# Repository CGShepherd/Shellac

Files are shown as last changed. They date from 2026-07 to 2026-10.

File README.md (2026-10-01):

# Project Shellac

Shellac is a controlled 78 rpm replay preamplifier design. `develop` is the working engineering authority; a tagged `main` release becomes production authority only after qualification and reproducibility gates close.

## Current authority

Read these first:

1. `config/decisions/current_decision_index.yaml`
2. `config/decisions/document_authority.yaml`
3. `docs/knowledge/DESIGN_PACK_INDEX.md`
4. current `generator/`, BOM and tests
5. current pre-SPICE assurance records in `docs/design_pack/`

Historical records are provenance and do not override later current authority.

## Live implementation versus selected-next architecture

- DR-037 complete RIAA: implemented.
- DR-038/SCH101: AE-071A migrates the fail-safe 14/18/22 dB removable-shunt architecture and BASE/+47/+100 pF loading; AE-075B selects LT5400BIMS8E-7#PBF, bonds EP9 to quiet 0VA and selects compatible Samtec TSW/MNT service hardware. RUN10 complete-stage tolerance/CMRR, physical shunt pairing/orientation, short-route parasitics and bench qualification remain open.
- DR-039/SCH107: AE-074 migrates the AE-067 branch-local topology into the live generator: the retained 1 uF / 330 kOhm network exists only in each DIRECT/BYPASS branch, while the existing SCH107 high-pass branch provides intrinsic DC blocking. Native-PCB F8/net reconciliation is closed by AE-074; RUN09, RUN10, RUN12 and bench correlation remain open.
- SCH108/output interface: AE-075G implements exact Molex 5055780221 two-circuit PCB headers H801/H802 for the short rear-panel balanced-output looms, validates HOT/COLD native pad mapping with no 0VA conductor, corrects THAT1646 source semantics to 25 Ohm per leg / 50 Ohm differential, and passes the application-specific PRE90 2 kOhm load discriminator. H801/H802 XY remains provisional pending manual placement reconciliation; RUN06 load/cable stability and dynamic-THD bench gates remain open.
- AE-041 A1 + AE-075C hardware + AE-076B controls: exact NKK/C&K hardware remains frozen. AE-076B supersedes the AE-075D/E/F four-local-control-board/carrier-era ownership architecture with one main audio PCB carrying all seven controls directly; the upper cover, main PCB and controls form one removable service module. Six PCB-to-upper-cover supports are selected in principle, but exact support XY/Z, the C&K fit at the NKK-constrained control plane, control XY, footprints/courtyards, panel apertures and RUN10 parasitic acceptance remain B03-open. SR-040/AE-071B MH1-MH4 native geometry is retained only as interim physical CAD pending the AE-076B2 MCAD/digital-mock-up migration; no control inter-board harnesses are selected.
- SW905 mute: mechanical DPDT signal/0VA selection immediately before the THAT1646 drivers. No relay/timer/comparator architecture.

Do not change live circuitry merely to make it resemble a selected-next record. Migration requires a controlled qualification and implementation step.

## Power and grounding

AE-076A establishes +17.0 V / 0VA / -17.0 V as current Shellac regulated-rail authority and migrates the live generator, current simulation contract, commissioning expectations and native PCB rail identities together. Historical +/-18 V assurance evidence remains immutable provenance. AE-073's target-17 PSU discriminator remains supporting model evidence only: powered set-point, dropout, ripple, startup and thermal qualification remain open under RUN13/RUN14 and bench work. The selected direct 0VA-to-chassis population remains R909 = 0 Ohm fitted, with C909, D901 and D902 DNP. Shellac and Phoenix are independent designs.

## Simulation

AE-053 defines the LTspice/Python simulation architecture. AE-054 through AE-058 establish implemented toolchain and numerical-correlation evidence. The integrated full-system campaign remains governed by AE-048 and AE-050 with AE-049 retained as the historical numerical-acceptance basis; AE-076A narrowly supersedes the current nominal-RUN00 rail criterion at +17 V / 0VA / -17 V and adds targeted rail/headroom requalification. Analytical Python is an independent live-state regression/correlation aid, not final integrated analogue authority.

## Basic validation

    python -m pytest -q
    python tools/audit_current_decision_index.py
    git diff --check

This repository is not yet a manufacturing baseline.

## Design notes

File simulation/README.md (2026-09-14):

# Project Shellac — Controlled LTspice/Python Toolchain

This directory implements the AE-053 simulation architecture under the governing
qualification/acceptance/execution authorities AE-048, AE-049 and AE-050.

Stage 1 scope is deliberately narrow:

- controlled tool/version discovery;
- deterministic run configuration;
- model/include provenance and SHA-256 manifests;
- reproducible LTspice batch invocation;
- structured measurement extraction;
- central acceptance mapping;
- RUN00 model-sanity harness;
- anomaly recording;
- deterministic rerun comparison.

This stage does **not** implement DR-038 or DR-039 circuit changes and does not
constitute manufacturing authority.

## First use

From the repository root:

```cmd
python -m simulation.scripts.shellac_spice doctor
python -m simulation.scripts.shellac_spice manifest
python -m simulation.scripts.shellac_spice prepare RUN00
```

If LTspice is installed and discovered:

```cmd
python -m simulation.scripts.shellac_spice run RUN00
python -m simulation.scripts.shellac_spice verify RUN00
```

If LTspice is not auto-discovered, set `LTSPICE_EXE` to the full executable path.

Generated artefacts live under `simulation/generated`, `simulation/results`,
`simulation/logs`, and `simulation/plots`. They are reproducible artefacts rather
than hand-edited design authority.

RUN00 is a toolchain/invocation sanity circuit, not the final integrated Shellac model.
Its purpose is to prove the controlled execution path before real block models are added.

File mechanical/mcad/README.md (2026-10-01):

# Shellac MCAD workspace

AE-076B2 controls this workspace.

METCASE M5502119:
- public official PDF drawing is hash-controlled;
- exact STEP requires METCASE authentication and is ingested/hash-controlled by AE-076B2B;
- drawing-to-STEP dimensional reconciliation remains open.

Neutrik panel STEP models and the governed KiCad PCB STEP live only in ignored
local evidence caches.

Reproduce public/local inputs with:

    .venv\Scripts\python.exe tools\prepare_ae076b2b_mcad_inputs.py

After manually downloading M5502119.stp while logged in to METCASE:

    .venv\Scripts\python.exe tools\prepare_ae076b2b_mcad_inputs.py --verify-only --ingest-metcase-step "C:\path\M5502119.stp"

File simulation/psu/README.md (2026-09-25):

# Shellac PSU simulation

The PSU simulation namespace separates manufacturer-macromodel execution qualification
from physical PSU qualification.

- `config/p1v.yaml` is the current AIYIMA P1-V physically reconstructed authority,
  pending powered validation.
- `RUN00_QUALIFICATION.md` records the controlled model-execution qualification.
- RUN00 is PASS locally; AE-073 closes the long-settle discriminator and confirms
  that the exploratory 400 ms low-output condition was a startup-settling artefact,
  not a demonstrated DC adjustment ceiling. Powered hardware qualification remains open.
- Compact AE-073 evidence is retained under `evidence/ae073_long_settle/`.
- Vendor model payloads are local only and are not committed.
- The governing philosophy is retain the as-fitted PSU unless quantitative analysis
  or measurement identifies a material safety, reliability, stability, noise,
  regulation, thermal, protection or operating-margin deficiency.

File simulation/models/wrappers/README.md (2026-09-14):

# Model wrappers

Controlled wrappers/adaptors around unchanged reference models belong here.

A wrapper must state:
- reference model wrapped;
- interface/pin mapping;
- reason;
- limitations;
- claims for which it is suitable.

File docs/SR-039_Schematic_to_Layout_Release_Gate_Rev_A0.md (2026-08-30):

# SR-039 — Schematic-to-Layout Release Gate — Rev A0

## Executive disposition

Project Shellac's electrical/schematic design is **released for layout work**.

Validated baseline:
- 374 / 374 Python regression tests;
- successful generated KiCad project build;
- native KiCad ERC: **0 errors, 0 warnings**.

DR-037, DR-038, DR-039 and DR-040 are treated as implemented. The signal-chain
architecture is frozen for layout unless a new controlled defect is demonstrated.

## Released now

- SCH101 precision balanced front end with 4.000x LT5400-7 architecture.
- SCH103 complete replay EQ and DR-039 common post-EQ DC isolation.
- SCH107 rumble filter.
- SCH104 final gain.
- SCH105 channel-mode matrix.
- SCH108 balanced output and mute.
- SCH109 controls/interfaces.
- Four-layer analogue PCB architecture and critical-net policy.

## Not yet released

### Final routing
The active board-outline model still uses provisional mechanical datums.
Critical-cluster placement may proceed inside the conservative provisional
220 x 140 mm keep-in, but mounting holes, enclosure intrusion keep-outs and final
harness corridors must not be invented.

### Manufacturing
The controlled BOM remains a partial high-level baseline rather than a full
schematic-population procurement BOM. Manufacturing release therefore requires
exact identities, quantities, footprints and procurement state for the complete board.

## Layout-critical constraints

SCH101:
- preserve cartridge-pair symmetry through RF filtering;
- keep each LT5400 adjacent to its OPA1656 converter;
- PLUS_SUM / MINUS_SUM and PRE_EQ feedback/output nodes are manual, zero-via critical nets;
- no power/control copper through the cartridge or LT5400 summing region.

SCH103:
- C360/C410 1 uF DR-039 film capacitors and R360/R410 330 k bias resistors
  stay at the recovery-output / POST_EQ hand-off;
- timing/selector branches remain local to each channel;
- preserve physical separation between left and right EQ islands.

SCH107:
- frequency-setting passives remain tight to the OPA1656 stage.

SCH108:
- THAT1646 OUT/SNS loops remain direct, local and zero-via where practicable.

Power / ground:
- Inner-1 remains continuous 0VA.
- CHASSIS is not a signal-current return.
- ±18 V load returns must not traverse cartridge/EQ reference regions.

## Next phase

SR-040 is the **mechanical-datum + full-BOM + critical-placement closure**.
It should end with:
1. frozen board outline and mounting holes;
2. full keep-out map;
3. complete BOM/footprint/procurement reconciliation;
4. accepted placement of all critical analogue clusters;
5. routing release.

Once SR-040 closes, routing should start immediately.

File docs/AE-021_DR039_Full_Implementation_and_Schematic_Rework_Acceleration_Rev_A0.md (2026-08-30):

# AE-021 — DR-039 Full Implementation and Schematic-Rework Acceleration

This phase closes DR-039 as an implemented subsystem rather than another analysis increment. SCH103 gains a common 1 µF PET-film / 330 kΩ DC block per channel before the SCH107 FILTER/BYPASS split, with raw and post-block test points. The nominal pole is approximately 0.48 Hz and is negligible at 20 Hz.

Physical capture uses the WIMA MKS2 1 µF / 63 V class, 5 mm lead pitch, approximately 7.2 × 5 × 10 mm.

After this phase, the only major signal-chain schematic rework before layout is DR-038 SCH101 precision migration. The next phase is intentionally large: LT5400-7 CAD representation, 4x converter, 1 kΩ gain ladder, hard service links, RF matching, SCH101 capture rewrite, placement/BOM updates, and CMRR/noise/headroom regression.

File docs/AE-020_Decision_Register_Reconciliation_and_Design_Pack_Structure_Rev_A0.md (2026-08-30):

# AE-020 — Decision Register Reconciliation and Design-Pack Structure

**Revision:** A0  
**Status:** CONTROL STRUCTURE PROPOSED FOR ADOPTION  
**Baseline:** `main` at `1ebb04d`

## Finding

AE-019 correctly exposed ambiguity, but much of that ambiguity comes from narrative documents mentioning selected and rejected alternatives in the same file. Status cannot therefore be inferred reliably from keyword occurrence.

The repository needs a machine-readable authoritative current-status index separate from historical narrative evidence.

## Resolution

AE-020 introduces:

- `config/decisions/current_decision_index.yaml` — authoritative current decision status;
- `docs/knowledge/DESIGN_PACK_INDEX.md` — how to read the controlled pack;
- `docs/maintenance/MAINTENANCE_GUIDE_SKELETON.md` — future service-document structure.

No historical decision or AE document is rewritten.

## Key reconciled statuses

- DR-037: **CURRENT_IMPLEMENTED**
- DR-038: **CURRENT_SELECTED_PENDING_IMPLEMENTATION**
- DR-039: **CURRENT_SELECTED_PENDING_IMPLEMENTATION**
- DR-040: **CURRENT_SELECTED_PENDING_IMPLEMENTATION**
- AE-016 implementation attempt: **SUPERSEDED by the repair/staging evidence**

This explicitly separates design intent from implemented hardware.

## Next documentation phase

After DR-038/039 atomic migration closes, the decision index must be changed in the same merge from selected/pending to implemented, and the maintenance guide populated with the new service links, DC-block behaviour, CMRR/noise limits and commissioning checks.

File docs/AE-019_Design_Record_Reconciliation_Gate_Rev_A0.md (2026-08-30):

# AE-019 — Design Record and Decision Register Reconciliation Gate

**Status:** READ-ONLY AUDIT

This audit runs in parallel with signal-chain revalidation. It inventories controlled decision and assurance records without rewriting history. The eventual design pack will distinguish the current design baseline, decision register, assurance evidence, production/commissioning record, maintenance guide, and historical archive.

Run `python tools/ae019_design_record_reconcile.py`, then `python -m pytest`. Review the generated report before changing any decision status.

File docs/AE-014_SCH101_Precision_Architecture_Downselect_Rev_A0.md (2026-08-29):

# AE-014 — SCH101 Precision Architecture Down-Selection

**Revision:** A0  
**Status:** DESIGN RECOMMENDATION — ready for schematic implementation after owner acceptance  
**Date:** 29 August 2026  
**Base commit:** `27f0a0eb641347925cb5e99e2c4f821553961bac`

## Executive conclusion

AE-013 identified two coupled weaknesses in the controlled SCH101 implementation: resistor-network Johnson noise and tolerance-limited CMRR.

AE-014 recommends solving both without changing the fundamental balanced-input topology or the established 14/18/22 dB user gain choices.

**Recommended architecture:**

1. retain the four OPA1656 non-inverting input legs;
2. reduce each leg's gain-setting impedance by approximately 10:1;
3. change the differential converter from the non-standard 3.48 ratio to a precision **4.000 ratio**;
4. implement the converter with **LT5400-7 A-grade, 1.25 kΩ / 5 kΩ**;
5. re-partition the selectable feedback ladder around **Rg = 1.000 kΩ**;
6. use **249 Ω fixed + 750 Ω DEFAULT addition + 1.91 kΩ HIGH addition**;
7. require approximately **0.01% relative matching** between corresponding gain-leg resistors.

This preserves the signal-chain gain budget while making a standard precision resistor network usable in the most CMRR-critical differential stage.

## 1. Why 4.00x rather than retaining 3.48x

The controlled 3.48x converter uses 10 kΩ / 34.8 kΩ. It is electrically valid but awkward as a high-precision monolithic ratio.

Analog Devices' current LT5400 catalogue provides standard ratios including 1:1, 1:4, 1:5, 1:9 and 1:10. The LT5400-7 is **1.25 kΩ / 5 kΩ = 1:4**. A-grade parts specify 0.01% general matching and 0.005% matching under the datasheet CMRR definition, with very low matching drift.

Moving to 4x therefore replaces an awkward custom precision ratio with a standard, characterised difference-amplifier network.

The required total gain is then restored in the preceding non-inverting legs.

## 2. Candidate realised gains

| Setting | Total RF per leg | Realised SCH101 gain | Error from target | Input-referred white-noise estimate | Deterministic CMRR floor* |
|---|---:|---:|---:|---:|---:|
| LOW | 249 Ω | 13.972 dB | -0.028 dB | 10.32 nV/√Hz | 78.4 dB |
| DEFAULT | 999 Ω | 18.057 dB | +0.057 dB | 9.21 nV/√Hz | 72.4 dB |
| HIGH | 2159 Ω | 22.032 dB | +0.032 dB | 8.88 nV/√Hz | 70.1 dB |

\* Corner model combines 0.01% gain-leg ratio uncertainty and 0.005% differential-converter CMRR matching. It does not include PCB, RF capacitor or switch parasitic imbalance.

All three established system gain choices remain within 0.07 dB of target. No downstream gain/headroom philosophy changes.

## 3. Gain ladder

Candidate per leg:

- Rg = 1.000 kΩ;
- LOW: RF = 249 Ω;
- DEFAULT: RF = 249 Ω + 750 Ω = 999 Ω;
- HIGH: RF = 249 Ω + 1.91 kΩ = 2.159 kΩ.

Resulting per-leg gains are approximately 1.249x, 1.999x and 3.159x. With the 4x converter these realise approximately 14, 18 and 22 dB total SCH101 gain.

The existing two-bit selector logic can therefore be retained conceptually. The switch still selects matched added feedback segments across all four balanced legs.

## 4. Precision-network strategy

### Differential converter — DOWN-SELECTED

**Preferred:** Analog Devices LT5400-7 A-grade.

Reasons:

- exact standard 1:4 ratio;
- 1.25 kΩ / 5 kΩ values are already in the desired low-noise impedance region;
- 0.01% A-grade matching;
- datasheet CMRR matching specification of 0.005%;
- 0.2 ppm/°C typical matching drift and ±1 ppm/°C maximum specification;
- MSOP-8 footprint;
- explicitly intended for difference-amplifier service;
- recommended for new designs by Analog Devices.

The exposed pad is electrically floating according to the datasheet. Layout should follow the manufacturer's symmetry guidance and avoid thermal gradients across the package.

### Gain legs — PREFERRED POLICY, PART FAMILY NOT YET FROZEN

The four corresponding resistors for each segment should track one another. There are three useful implementation levels:

**A — preferred production solution:** four-equal-resistor thin-film network per segment, 0.01% ratio class. Vishay MORN is technically attractive: four isolated resistors, ratio tolerance to 0.01%, tracking to 1 ppm/°C typical / 2 ppm/°C maximum, 400 Ω–100 kΩ per element, with factory consultation for additional values. The 249 Ω LOW segment is below the stated MORN 400 Ω range, however, so MORN cannot implement the complete proposed ladder unchanged.

**B — practical prototype solution:** individually selected 0.01% thin-film resistors for the 249 Ω / 750 Ω / 1.91 kΩ segments, placed as geometrically and thermally matched quartets. This meets the AE-014 deterministic tolerance model but has weaker guaranteed temperature tracking than a monolithic network.

**C — ACAS arrays:** Vishay ACAS is readily attractive mechanically and offers four isolated elements, but standard ACAS relative tolerance is 0.05%, not the 0.01% assumed by the preferred CMRR model. It is therefore not sufficient by itself for the final gain-leg precision target.

## 5. Alternative considered: preserve 3.48x

Retaining 3.48x would minimise mathematical change, but it forces either:

- custom precision networks;
- independent ultra-precision resistors with poorer thermal tracking;
- or a relaxed CMRR guarantee.

The 4x solution is cleaner because the precision-critical difference ratio becomes a standard catalogue component and the gain correction occurs in low-noise non-inverting feedback.

**Recommendation: reject the 3.48x converter for the next SCH101 revision.**

## 6. Noise consequence

AE-013 estimated the current DEFAULT front end at roughly 18 nV/√Hz input-referred.

The AE-014 candidate is below 9.5 nV/√Hz in the same first-order model. The improvement is approximately 6 dB and comes mainly from lowering the feedback/difference-network impedances.

This is a worthwhile improvement even though record surface noise will dominate practical 78-rpm replay.

## 7. Switch resistance sensitivity

The feedback-selector contacts are in series with selected RF additions. At approximately 1 kΩ-scale impedances, contact resistance matters more proportionally than in the original 10 kΩ-scale network.

Therefore the schematic implementation must not blindly retain the present DIP-switch assumption. The next implementation review shall:

- establish maximum and tracking contact resistance;
- place the switch so that any contact resistance appears symmetrically in corresponding legs;
- determine whether a sealed low-resistance DIP/relay arrangement is preferable;
- include contact resistance in gain-match/CMRR corners.

This is the principal new trade introduced by the lower-impedance ladder.

## 8. RF network and source balance

The two 100 Ω input series resistors and common-mode 1 nF capacitors must also be treated as a matched differential pair if high-frequency CMRR is to be meaningful.

The current 1% 100 Ω parts are acceptable for RF isolation but are not compatible with claiming a precision wideband CMRR number without further analysis.

Recommendation for the next schematic pass:

- move the two 100 Ω series resistors to 0.1% thin film or a matched pair;
- retain C0G/NP0 dielectric;
- use matched/tight-tolerance common-mode capacitors and symmetric placement;
- model the 220 pF differential capacitor separately because its mismatch mechanism differs.

## 9. Proposed acceptance requirements

AE-013 found no controlled system CMRR requirement. AE-014 therefore proposes requirements for formal adoption:

- **CMRR ≥ 70 dB from 20 Hz to 1 kHz** at all three gain settings;
- **CMRR ≥ 60 dB at 20 kHz**;
- DEFAULT SCH101 input-referred electronics noise target **≤ 10 nV/√Hz at 1 kHz**, excluding cartridge Johnson noise where measurement methodology requires;
- gain accuracy **±0.10 dB** at each gain setting;
- inter-leg/channel gain matching sufficiently tight that the above CMRR limits are met without calibration.

These are proposed engineering requirements, not retroactive baseline claims.

## 10. Decision state

Recommended for owner acceptance:

**DR-038 — SCH101 precision architecture**
- replace 3.48x converter with 4.00x precision converter;
- LT5400-7 A-grade preferred;
- reduce gain-ladder impedance around Rg = 1 kΩ;
- preserve 14/18/22 dB total gains;
- require 0.01% class gain-leg ratio control;
- requalify selector contact resistance and RF-input matching.

No SCH101 schematic is modified by this package. This keeps the design-history boundary clean: analysis/down-selection first, implementation after acceptance.

## 11. Next implementation phase

After DR-038 acceptance:

1. revise `balanced_input.py`;
2. revise SCH101 builder and footprints;
3. select exact gain resistor technology and switch;
4. extend CMRR model with switch resistance and RF tolerances;
5. rerun AE-012 headroom regression;
6. rerun AE-013/014 noise regression;
7. then continue full-chain integrated noise through SCH103, SCH107, SCH104, SCH105 and SCH108.

## Sources consulted

- Analog Devices, LT5400 product page and LT5400 Rev C datasheet.
- Vishay, MORN precision resistor-network datasheet/product page.
- Vishay, ACAS 0612 / ACAS 0612 AT precision-array datasheets/product pages.

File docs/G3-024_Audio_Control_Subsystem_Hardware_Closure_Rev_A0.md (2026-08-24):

# G3-024 — Audio Control Subsystem Hardware Closure

**Revision:** A0  
**Status:** candidate for controlled merge  
**Base:** SR-036 / `2728729f96166abf521d332aec886016555fd057`

## Objective
Close physical hardware selection for the five external operating switches and two rail indicators without inventing the still-unrecovered internal 3180 us RIAA switch topology or prematurely releasing PCB/drilling geometry.

## External controls
- SW901 Bass — Grayhill `71BDF30-01-2-AJN`, adjustable stop at 5.
- SW902 Treble — same exact MPN, adjustable stop at 5.
- SW903 Channel Mode — Grayhill `71BDF30-02-2-AJN`, two decks/four poles total, adjustable stop at 4.
- SW904 Rumble — C&K `7201SYCBE`, DPDT ON-ON, PC pins, threaded bushing, gold contacts.
- SW905 Mute — same exact C&K `7201SYCBE`.

All five are intended as PCB-mounted controls with bushings through the top cover. PCB standoffs define the board datum; the bushings are intentional secondary structural connections and must not pull a misaligned PCB into position.

## Rail indicators
LED901 and LED902 are fitted only to the audio chassis, on the top-cover longitudinal centre spine, as a symmetric pair. Selected LED is Vishay `TLLG4401`, 3 mm diffused green low-current type. Selected holder is Arcolectric/Bulgin `A104700BLACK`, black-finished brass 3 mm bezel.

Retain 8.2 kΩ current limiting. With a 2.4 V design forward voltage, nominal current is about 1.90 mA from an 18 V rail. This deliberately targets subdued indication. LEDs use short flying leads; no light pipes are used.

## Representation boundary
The existing SCH109 builder remains a generic electrical/interface representation and is not yet placement authority. G3-024 updates the engineering model/BOM with selected hardware. Verified custom footprints, 3D envelopes and final PCB/top-cover coordinates remain for the next physical-board package.

## Internal RIAA ON/BYPASS
Recovered intent is retained: the later 3180 us / 50 Hz RIAA function is separately switchable internally and BYPASS is straight-through. It is not implemented by adding a third pole to the Bass rotary. The controlled SCH103 evidence does not yet identify the exact nodes or pole count, so G3-024 intentionally does not nominate an SPDT/DPDT topology or MPN.

## Acceptance
- selected external hardware exists in the controlled BOM/model;
- model no longer describes only generic top-panel controls;
- tests assert switch commonality, structural ownership and low-current LED implementation;
- RIAA topology and footprint/drilling authority remain explicitly open;
- full regression passes.

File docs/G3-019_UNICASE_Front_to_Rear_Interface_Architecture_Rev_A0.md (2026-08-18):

# G3-019 — UNICASE Front-to-Rear Interface Architecture — Rev A0

## Objective

Freeze the enclosure-family, panel ownership, signal-flow direction, PCB-mounted control philosophy, and drilling-template contract before exact enclosure sizes and control coordinates are committed.

This change does **not** freeze either enclosure order code and does not release any hole coordinates for manufacture.

## Enclosure family decision

Project Shellac now uses the **METCASE UNICASE** family in **black RAL 9005** as the selected enclosure architecture for both the main audio chassis and the external PSU.

METCASE describes UNICASE as an aluminium total-access instrument enclosure with removable top/base panels, a removable internal chassis, PCB guide rails, and anodised front/rear panels. The current audio-size candidate is black UNICASE 2 `M5502119`, for which METCASE publishes 260 x 250 x 90 mm external dimensions and a 241 x 229 mm base-PCB capability. Exact usable control stack-up, panel intrusion, mounting geometry and final order-code fit remain drawing-gated.

Manufacturer references:

- https://www.metcase.co.uk/en/Metal-Enclosures/Unicase.htm
- https://www.metcase.co.uk/en/Unicase/M5502119.htm

## Main audio chassis architecture

The physical signal direction is now **front to rear**.

- Front panel: left/right cartridge input XLRs.
- Front board edge: balanced-input/RF region immediately behind the input connectors.
- Middle board bands: replay EQ, rumble filtering, final gain/mode processing.
- Rear board edge: mute/balanced-output regions.
- Rear panel: left/right output XLRs.
- Rear panel near centreline: regulated DC inlet and local chassis-bond region.
- Upper cover: operator switch/potentiometer shafts or bushings and indicators/light pipes.

The old right-to-left board-flow convention is superseded.

## Control mounting

All operator switches and potentiometers are PCB mounted. No flying switch/potentiometer harness is permitted.

Where a suitable component is available, a threaded bushing should pass through the upper cover and be retained by its washer/nut. The bushing provides location and secondary mechanical support **only after** the PCB position has been established by its own mounting datums. The nut must never be used to pull an offset PCB into alignment.

Plain-shaft PCB controls remain an allowed fallback if required by electrical/component quality constraints.

PCB-mounted LEDs with light pipes are preferred. A flying indicator lead is permitted only if a suitable PCB/light-pipe solution cannot be achieved and that exception is explicitly reviewed.

## PSU architecture

PSU physical flow is **rear to front**.

- Rear panel: IEC/filter/switch and mains entry.
- Rear internal zone: protective earth and mains wiring.
- Transition: toroidal transformer.
- Forward internal zone: rectification/regulation.
- Front panel: regulated low-voltage DC output.

The top/base clamshell panels should remain unmachined if the selected UNICASE size permits the complete transformer, regulator, wiring, segregation and thermal layout.

## Preliminary placement reorientation

The coarse placement synthesis now treats board Y as the front-to-rear direction. Inputs occupy the front band. Left/right replay networks occupy the next band. Rumble/final-gain/control logic occupy the middle band. Balanced outputs and regulated-DC entry occupy the rear band, with DC entry reserved near the centreline.

The previous CLU-106 left-edge macro coordinates are intentionally discarded because they encode the superseded enclosure orientation. CLU-106 returns to deterministic manual-review placement until exact rear-panel/DC-entry geometry is frozen.

## Drilling-template contract

Case drilling templates are generated mechanical outputs, not hand-dimensioned workshop sketches.

Released templates must:

- use a manufacturer-defined enclosure/panel datum rather than chained hole-to-hole dimensions;
- be supplied as 1:1 PDF and DXF;
- include switch/pot bushing centres and finished hole diameters;
- include anti-rotation features where required by selected hardware;
- include indicator/light-pipe apertures;
- include front/rear XLR/DC and PSU IEC/DC connector cut-outs;
- include datum/centre lines and check dimensions;
- include a 100 x 100 mm calibration box;
- state `PRINT AT 100% / ACTUAL SIZE — DO NOT FIT TO PAGE`;
- verify PCB-to-cover stack-up and bushing thread engagement before drilling.

No manufacturing drilling template may be released until exact UNICASE order codes, PCB/control coordinates, control part numbers, panel thickness and manufacturer drawings are frozen.

## Status after G3-019

Frozen:

- METCASE UNICASE family;
- black RAL 9005 finish;
- main-chassis front-to-rear signal direction;
- front input / rear output + DC panel ownership;
- PCB-mounted operator controls through the upper cover;
- PSU rear-mains/front-DC direction;
- datum-based drilling-template requirements.

Still open:

- exact audio UNICASE order code;
- exact PSU UNICASE order code;
- exact switch/potentiometer families and bushing stack-up;
- final indicator/light-pipe implementation;
- released hole coordinates and templates;
- final carrier/chassis mounting decision after exact UNICASE drawings are overlaid.

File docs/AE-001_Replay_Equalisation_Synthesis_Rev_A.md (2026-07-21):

> **SUPERSEDED by AE-002 Rev A. Do not use the 14.3 kΩ bass-network values below.**

# Project Shellac — AE-001 Replay Equalisation Synthesis

**Revision:** A  
**Status:** switched frequency-setting networks approved; complete SCH103 not yet frozen  
**Date:** 14 July 2026

## 1. Purpose

This report replaces the provisional copying of ESP Project 91 capacitor
values with independently calculated Project Shellac networks.

The calculation uses:

\[
f = \frac{1}{2\pi RC}
\]

The Project 91 table remains the source for the selected replay break
frequencies. Project 06 provides the underlying active-bass/passive-treble
architecture and the updated 750 ohm / 100 nF RIAA treble network.

## 2. Design decisions

### Bass network

A fixed **14.3 kΩ, 0.1% metal-film resistor** is used for the switched bass
capacitors. It provides close realisation of 200, 400 and 500 Hz using common
main capacitor values and inexpensive C0G trim capacitors.

### Treble network

A fixed **750 Ω, 0.1% metal-film resistor** is retained from the updated
Project 06 recommendation. All treble selections are recalculated around that
resistor instead of retaining the older Project 91 capacitor table unchanged.

## 3. Approved network values

| Section | Selection | Fixed R | Capacitor implementation | Total C | Realised | Error |
|---|---:|---:|---:|---:|---:|---:|
| Bass | Flat | — | Switch short | — | — | — |
| Bass | 200 Hz | 14.3 kΩ | 56 nF | 56.00 nF | 198.745 Hz | −0.628% |
| Bass | 400 Hz | 14.3 kΩ | 27 nF + 820 pF | 27.82 nF | 400.062 Hz | +0.015% |
| Bass | 500 Hz RIAA | 14.3 kΩ | 22 nF + 270 pF | 22.27 nF | 499.763 Hz | −0.047% |
| Treble | Flat | — | Switch open | — | — | — |
| Treble | 1,600 Hz | 750 Ω | 120 nF + 12 nF | 132.00 nF | 1,607.626 Hz | +0.477% |
| Treble | 2,121 Hz RIAA | 750 Ω | 100 nF | 100.00 nF | 2,122.066 Hz | +0.050% |
| Treble | 3,400 Hz | 750 Ω | 56 nF + 6.2 nF | 62.20 nF | 3,411.682 Hz | +0.344% |
| Treble | 5,800 Hz | 750 Ω | 33 nF + 3.6 nF | 36.60 nF | 5,797.994 Hz | −0.035% |

The worst break-frequency error is **0.628%**.

This is materially tighter than simply reusing the Project 91 source
capacitors with a changed resistor baseline, while requiring no exotic
values.

## 4. Component implementation

- Fixed resistors: 0.1% metal film, 1206 preferred.
- Main capacitors: film or C0G/NP0, selected for low loss and stability.
- Trim capacitors: C0G/NP0.
- Left/right aggregate capacitance should be matched to 0.5% or better.
- Parallel components shall be placed adjacent to one another and to the
  switch/core node.
- Rotary-switch wiring shall remain extremely short, as required by P91.

The use of two parallel capacitors is deliberate. It gives better accuracy
with readily available values and allows channel matching without purchasing
special-value capacitors.

## 5. Replay coverage

The approved switch positions cover the practical groupings identified in
Project 91:

- flat/acoustic;
- bass turnover at 200, 400 and 500 Hz;
- treble flat, 1,600, 2,121, 3,400 and 5,800 Hz.

The controls remain independently selectable, allowing the operator to choose
the closest documented characteristic and then optimise by listening where
recording practice departed from nominal standards.

## 6. Items not yet approved

This report does **not** freeze:

1. SCH103 active-stage gain;
2. complete signal-chain gain allocation;
3. overload margin;
4. noise contribution;
5. the circuit topology and values for the bypassable 50.05 Hz / 3180 µs
   RIAA bass-flattening pole;
6. the final post-EQ gain setting.

Those items form AE-001B. They must be reconciled with the approximately
17–18 dB THAT1512 input-stage gain before the detailed LM4562 core is generated.

## 7. External references

- ESP Project 91, *Multi Standard 78 RPM and RIAA Phono Equaliser*:
  `https://sound-au.com/project91.htm`
- ESP Project 06, *Hi-Fi Phono Preamp (RIAA Equalisation)*:
  `https://sound-au.com/project06.htm`

Accessed 14 July 2026. The source material is used for this personal
construction project under the conditions stated by its author.

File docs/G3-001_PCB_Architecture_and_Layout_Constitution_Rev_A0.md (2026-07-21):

# G3-001 — PCB Architecture and Layout Constitution Rev A0

**Status:** Provisional until the audio enclosure, board outline and mounting datums are frozen.

## Purpose

This baseline turns Gate 3 layout intent into a CAD-independent, testable model. It does not place components or emit a KiCad PCB. It defines what a future placement and routing implementation must preserve.

## Provisional stack-up

1. Top — components and critical analogue routing.
2. Inner 1 — continuous 0VA reference plane.
3. Inner 2 — ±18 V distribution with limited non-critical routing.
4. Bottom — supporting analogue and control routing.

Nominal construction is 1.6 mm FR-4 with 1 oz copper. Manufacturer-specific dielectric geometry and impedance values remain open because this design does not require controlled-impedance transmission lines.

## Placement sequence

Input/RF → Replay EQ L/R → Rumble filter → Final gain/mode matrix → Mute/balanced output → output harness.

DC entry and block-level bulk decoupling remain at the output/high-level end, remote from the cartridge input.

## Critical routing policy

Manual-only classes include cartridge inputs, op-amp feedback and frequency-setting nodes, replay-selector RC branches, THAT1646 OUT/SNS loops, 0VA and CHASSIS architecture.

Constrained automation may be used for panel controls and selected ordinary analogue or power routes, but every proposed route remains subject to engineering review.

## Mechanical assumptions

- Minimum usable PCB area: 190 × 125 mm.
- Preferred usable PCB area: 220 × 140 mm.
- Board-edge clearance: 5 mm provisional.
- Mounting-hole keep-out: 10 mm provisional.
- Audio enclosure lid or base must lift vertically after controls are installed.

## Generated evidence

Run:

```cmd
python scripts\report_layout_baseline.py
```

This writes `out/layout/layout_baseline.json`, which is the machine-readable baseline used by future placement and routing tools.

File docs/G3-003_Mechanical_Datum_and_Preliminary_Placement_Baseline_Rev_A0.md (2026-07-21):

# G3-003 — Mechanical Datum and Preliminary Placement Baseline

## Purpose

Create a controlled mechanical model before selecting catalogue enclosures or
committing component coordinates.

## Frozen intent

- Two-box architecture: separate PSU and audio enclosures.
- Audio enclosure: conductive metal; vertically removable lid/base after all
  controls and XLRs are fitted; external width not greater than 300 mm.
- PSU enclosure: conductive metal; sliding or extruded construction permitted.
- Both boxes use removable internal carrier plates where practical.
- Audio inputs remain at the right-side edge and outputs at the left-side edge.

## Mechanical datums

The model establishes carrier-plate origin, audio input edge, audio output edge,
control edge, chassis-bond point, and PSU protective-earth point.

## Candidate trade study

Candidate entries are deliberately classified as plausible, conditional,
rejected, or data-required. Unknown internal dimensions are treated as missing
evidence, not guessed.

## Placement synthesis

The preferred 220 × 140 mm usable board envelope is divided into non-overlapping
functional regions. The synthesis scales only within the minimum 190 × 125 mm
architecture. It is a region plan, not component placement or routing.

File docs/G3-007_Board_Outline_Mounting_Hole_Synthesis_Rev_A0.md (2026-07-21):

# G3-007 — Board-Outline and Mounting-Hole Synthesis Interface

## Purpose

Prevent plausible-looking manufacturing coordinates from being generated before
the audio enclosure and carrier plate are supported by authoritative drawings.

## States

- **PROVISIONAL:** board architecture and coordinate convention only; no holes.
- **DECISION_READY:** reserved for complete evidence awaiting formal approval.
- **FROZEN:** board outline and four datum-referenced mounting holes derived from
  an approved carrier-plate freeze.

## Frozen Rev A mounting contract

- four non-plated 3.2 mm finished holes;
- 8.0 mm copper keep-out diameter;
- rectangular pattern measured from the lower-left PCB origin;
- default 8.0 mm inset from each board edge;
- component-side coordinate view;
- board remains vertically removable from the audio enclosure.

Exact values remain provisional until an enclosure and carrier plate are frozen.

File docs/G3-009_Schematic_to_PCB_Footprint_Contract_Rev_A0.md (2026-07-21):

# G3-009 — Schematic-to-PCB Footprint Contract

The footprint contract separates approved PCB members, explicit panel/virtual
components and unresolved mechanical-interface components.  It exposes three
controlled ECO items: J101 and J201 input XLRs, and J901 five-pin regulated-DC
inlet.  These are electrically correct but mechanically inconsistent with the
agreed panel-mounted harness architecture.

The preliminary population export omits all three until a controlled schematic
mechanical-ownership ECO is approved.  The accepted electrical topology and
native ERC baseline remain unchanged.

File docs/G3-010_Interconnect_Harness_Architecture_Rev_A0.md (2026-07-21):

# G3-010 — Interconnect and Harness Architecture Rev A0

## Decision

Project Shellac shall use two internal crimp-terminal families compatible with the user's SN-58B ratchet tool:

- JST VH (3.96 mm) for signal, control and indicator harnesses;
- Molex Mini-Fit Jr (4.2 mm) for regulated DC power.

The external two-box DC link remains a metal five-pin Neutrik XLR.

## Ownership ECO

J101, J201 and J901 remain electrical interface references but must not be populated as PCB-mounted XLR connectors. A controlled schematic ECO shall replace their PCB footprints with board-side harness interfaces while preserving signal names and pin assignments.

## Harness classes

- Microvolt analogue: shielded twisted pair or star-quad, AWG24, shortest route, 25 mm separation from power/control wiring.
- Line-level analogue: twisted pair, AWG22, routed in the output-side region.
- Regulated power: AWG18 Mini-Fit Jr, physically distinct, keyed by an unpopulated position.
- Control and indicator harnesses: JST VH, pin counts frozen after panel architecture.

## Shielding

Input and output XLR shells bond to chassis at panel entry. Signal returns remain separate from chassis. The external PSU cable uses both connector-shell bonding and a dedicated chassis conductor; neither shell continuity nor 0VA alone is relied upon as the chassis path.

## Crimp qualification

For every terminal/wire combination, make five samples and record:

1. terminal part number;
2. wire type and gauge;
3. SN-58B die cavity;
4. conductor-wing and insulation-wing inspection;
5. housing retention;
6. pull-test result.

Generic 'JST compatible' contacts are not approved substitutes without this qualification.

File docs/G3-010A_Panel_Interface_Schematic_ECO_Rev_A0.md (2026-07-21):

# G3-010A — Panel-Interface Schematic ECO

## Decision

Panel XLR connectors are mechanically owned by the enclosure, not the PCB.
The PCB receives those interfaces through detachable, crimped harnesses.

## Changes

### SCH101

- J101: left panel XLR, off-board.
- H101: left JST VH three-way PCB header.
- J201: right panel XLR, off-board.
- H201: right JST VH three-way PCB header.

The panel and board connector pins are connected one-to-one:

1. chassis/shield
2. signal hot
3. signal cold

### SCH106

- J901: panel five-pin regulated-DC XLR, off-board.
- H901: five-way Mini-Fit Jr PCB header.

Pin functions remain:

1. 0VA
2. +18VA input
3. -18VA input
4. chassis
5. reserved

## Consequences

- The footprint-contract freeze blockers are closed.
- Panel connectors cannot leak into PCB population.
- The cluster placement model now anchors to H101, H201 and H901.
- The external and internal connector families remain mechanically distinct.

This is a mechanical-ownership ECO. The analogue design is unchanged.

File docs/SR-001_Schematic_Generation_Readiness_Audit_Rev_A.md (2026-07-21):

# Project Shellac — SR-001 Schematic-Generation Readiness Audit

**Revision:** A  
**Status:** audit complete; Gate 2 not yet passed  
**Date:** 14 July 2026

## 1. Executive conclusion

All eight functional blocks have approved engineering models and registered
builders. This is **electrical-design closure**, not yet complete KiCad
schematic closure.

The present generated output is useful engineering evidence and layout
planning material, but it must not yet be treated as an ERC-capable connected
schematic baseline.

## 2. Audit findings

### Blocks with partial pin-level connectivity

- SCH101 Balanced Input
- SCH106 Power Entry

These builders emit wires, but still require final KiCad opening, symbol
resolution and ERC validation.

### Blocks still rendered as functional layouts

- SCH103 Replay Equalisation
- SCH104 Final Buffer
- SCH105 Mode Matrix
- SCH107 Rumble Filter
- SCH108 Balanced Output
- SCH109 Controls

These builders emit approved components, values, labels, notes and test-point
allocations, but currently emit no pin-level wires.

### Writer limitations

The current writer:

1. emits independent `.kicad_sch` files;
2. does not generate a root hierarchical schematic containing the eight sheet
   instances and hierarchical pins;
3. embeds definitions for only a subset of the custom symbols used by builders;
4. does not expose a general pin-coordinate and pin-net API;
5. cannot therefore support automated ERC as presently implemented.

## 3. Gate decision

Gate 2 — *First Complete Automatically Generated KiCad Project* — remains
**open**.

This does not reopen any approved analogue design. The remaining work is a CAD
renderer and connectivity implementation problem.

## 4. Critical-path corrective sequence

The minimum justified sequence is:

1. Define a pin-aware symbol contract for every functional symbol.
2. Extend `Component`/`Sheet` so builders connect named pins to named nets
   without manually calculating KiCad coordinates.
3. Embed or resolve every emitted symbol definition deterministically.
4. Convert the six functional-layout builders to pin-aware connectivity.
5. Generate a root hierarchical schematic and sheet pins from the Engineering
   Model interfaces.
6. Open the project in KiCad 9 and run ERC.
7. Correct genuine ERC findings and freeze the schematic baseline.

No PCB generation or placement work should start before those steps pass.

## 5. Process finding

The previous dashboard phrase “all eight blocks generated” remains true, but
“complete generated schematic” would be inaccurate. SR-001 adds an automated
gate so future status reports cannot conflate component placement with
electrical connectivity.

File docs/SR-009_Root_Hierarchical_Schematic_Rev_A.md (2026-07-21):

# Project Shellac — SR-009 Root Hierarchical Schematic Rev A

## Purpose

Generate one deterministic KiCad root schematic from the validated Engineering
Model and connect all eight pin-aware functional sheets without changing any
approved analogue circuit or component value.

## Implemented

- Eight hierarchical sheet instances, one per functional block.
- Hierarchical pins derived from each block interface.
- Matching hierarchical labels in every child schematic.
- Root-level labelled wire stubs providing cross-sheet net connectivity.
- Deterministic UUIDv5 identities for the root, sheet instances, sheet pins,
  hierarchy labels, root wires and root net labels.
- Child symbol-instance paths aligned with their root sheet instance UUIDs.
- Root and child page-instance records.
- Readiness audit updated to remove the resolved root-hierarchy blocker.

## Deliberate boundary

SR-009 does not reopen electrical engineering decisions.  Final KiCad symbol
resolution and ERC validation remain the next Gate 2 evidence activities.

## Acceptance evidence

- Existing SR-008 tests remain green.
- New hierarchy tests verify all block files, interfaces, labels and paths.
- Two independent builds produce byte-identical root schematics.
- KiCad 9 CLI can parse the generated hierarchy and export a netlist.

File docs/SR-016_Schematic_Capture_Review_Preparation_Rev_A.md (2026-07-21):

# Project Shellac - SR-016 Schematic Capture Review Preparation Rev A

## Status

Implemented and validated against the accepted SR-015 repository.

## Purpose

Move the generated project from electrically valid capture to a reviewable A3 schematic pack. This increment changes presentation and renderer behaviour only. It does not alter validated analogue values, gains, replay curves, control truth tables, supply voltages or signal-chain architecture.

## Review findings addressed

- Sheet notes were centred on their insertion point and clipped at the left border.
- Long net labels extended back over symbols and component references.
- SCH105 contained long diagonal signal connections.
- Decoupling components and panel indicators on several sheets entered the A3 title-block area.
- SCH101 gain-network components and its DIP selector were unnecessarily crowded.
- Non-physical hierarchy anchors cluttered functional sheets.
- Root connectivity labels duplicated the already-visible hierarchical pin names and crowded the gaps between sheet symbols.

## Changes

- Left-justify and consistently size sheet notes.
- Orient local label justification away from the connected wire stub.
- Reduce annotation and label typography to a consistent review scale.
- Add deliberate Manhattan routing for the SCH105 mode matrix.
- Spread the SCH101 gain and differential-converter presentation and move its DIP selector into clear space.
- Reposition SCH103 channels and all affected decoupling/indicator groups inside the usable A3 drawing area.
- Hide non-physical hierarchy-anchor annotations while preserving their electrical function.
- Hide redundant root local-label text while retaining deterministic root connectivity.
- Add regression checks for title-block clearance and orthogonal SCH105 signal routing.

## Evidence

- Python regression suite: 124 passed.
- Engineering Model: 8 blocks, 27 signals, validation passed.
- Model-driven build: 8 implemented blocks, 0 pending.
- Native KiCad hierarchical ERC: 0 violations.
- CAD-ready sheets: 8/8.
- Gate 2 schematic readiness: PASS.
- Consecutive clean builds remain byte-identical.
- Nine-page A3 PDF rendered and visually inspected for clipping, title-block intrusion, page completeness and routing presentation.

## Next review

Open the generated KiCad project and review the root plus all eight child sheets at normal working zoom. Record findings against the generator source. In particular, inspect dense internal net naming on SCH101 and SCH103, switch presentation, signal-flow readability and service/test-point identification before schematic freeze.

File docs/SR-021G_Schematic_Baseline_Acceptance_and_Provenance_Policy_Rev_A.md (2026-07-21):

# SR-021G — Schematic Baseline Acceptance and Provenance Policy

**Accepted parent:** SR-021F  
**Native KiCad ERC:** 0 errors, 0 warnings  
**Python tests:** 161 passed

The complete generated hierarchy is accepted as the first clean schematic
baseline. Provenance now distinguishes immutable generated design artifacts
from KiCad's mutable `.kicad_pro` editor state.

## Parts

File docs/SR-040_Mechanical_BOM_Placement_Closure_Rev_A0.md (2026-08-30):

# SR-040 — Mechanical Datum, Full-BOM Census and Critical Placement Closure — Rev A0

## Disposition

SR-040 closes the former audio-enclosure datum blocker using the authoritative
METCASE M5502119 Issue-1 manufacturer drawing.

The audio PCB is frozen at **220 x 140 mm** on a removable **231 x 219 x 2 mm**
carrier plate. The PCB lower-left origin is **(5.5, 39.5) mm** from the carrier
lower-left datum. Four non-plated M3-class PCB mounting holes are frozen at
5 mm X inset / 8 mm Y inset with 8 mm copper keep-out diameters.

This is a mechanical datum freeze, not a claim that every critical component
coordinate is accepted.

## Authoritative evidence

METCASE M5502119 / UNICASE 2:
- overall envelope 260 x 250 x 90 mm;
- manufacturer base PCB width 241 mm;
- inside-face depth 229 mm;
- internal cover height 86.2 mm;
- removable top, base and front/rear panels.

Source:
`https://www.metcase.co.uk/en/Unicase/M5502119/M5502119.pdf`

## BOM closure

SR-040 adds a generated census of **every schematic component** and its:
- reference;
- sheet;
- electrical value / device identity;
- assigned footprint;
- PCB/panel ownership;
- procurement-resolution state.

This deliberately distinguishes:
1. **design freeze** — electrical value and footprint fixed;
2. **procurement freeze** — exact manufacturer series/MPN fixed.

Generic resistors/capacitors do not block critical placement or routing merely
because the manufacturer MPN is still open, provided value, tolerance,
technology and footprint requirements are already controlled.

## Routing release

Mechanical datums are now frozen. The remaining routing gate is human acceptance
of the manual-authority analogue clusters generated by the existing placement
model, especially SCH101, SCH103, SCH107 and SCH108.

After that acceptance, routing should start immediately.

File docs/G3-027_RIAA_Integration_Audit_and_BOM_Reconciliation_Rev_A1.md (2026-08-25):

# G3-027 — Independent 3180-us Integration Audit and Foundry BOM Reconciliation

**Revision:** A1 — corrected independent-control interpretation  
**Base:** `e423121b8eba3b66b9f5c01c9e54e2c2f01fcffe`  
**Status:** candidate; electrical integration gate held

## Executive finding

The third RIAA pole is an **independent operator-controlled function**. It is not
interlocked with the Bass or Treble selectors, and G3-027 does not introduce any
logic that attempts to infer a “correct” replay setting.

The operator may therefore select any Bass position, any Treble position, and
optional 3180 us ON or BYPASS in any combination. An unusual combination is not an
electrical fault; it is simply an operator-selected replay curve.

The integration blocker is narrower. The controlled TRUE RIAA bass branch still
contains approximately the 3180 us pole and 318 us zero. G3-026 separately froze an
independent downstream 3180 us stage. If TRUE RIAA Bass is selected and that stage
is ON without changing the legacy branch, the 3180 us pole is applied twice.

Foundry therefore requires the TRUE-RIAA bass contribution to be resynthesised so
it **no longer contains the 3180 us pole**, while preserving the required 318 us
behaviour. The separate G3-026 3180 us stage can then sit later in the common signal
chain and remain completely independent of Bass/Treble selection.

No third Bass-selector pole is required by this interpretation.

## Required G3-028 electrical model

G3-028 should model the full Cartesian control space `Bass × Treble × optional-3180`,
not to prohibit unusual states, but to prove that each selector retains its defined
behaviour, ON contributes exactly one 3180 us term, BYPASS contributes none, TRUE-RIAA
Bass no longer embeds its own 3180 us pole, and no state applies the optional pole twice.

## BOM review

The current controlled BOM is a partial baseline, not a procurement-complete BOM.
A final cost total would therefore be false precision. G3-027 establishes a
procurement framework based on landed basket cost subject to Foundry requirements
and frozen MPNs.

Selected switches are bought at **required quantity only** by default. No routine
spares are purchased merely to reach quantity breaks. This remains valid while the
part is active/recommended for new designs and available without material supply
risk. NRND/EOL/obsolete status or genuine supply risk reopens the question.

## Controlled outcome

Closed: independent third-pole intent, no Bass/Treble interlock, executable
duplicate-3180 audit, required-quantity-only switch policy, partial-BOM status and
landed-cost procurement rules.

Held: TRUE-RIAA Bass resynthesis, SCH103 ECO, complete independent-state regression,
final footprint/machining work and final procurement BOM.

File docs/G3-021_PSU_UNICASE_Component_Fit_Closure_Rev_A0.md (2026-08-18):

# G3-021 — PSU UNICASE Component-Fit Closure — Rev A0

## Objective
Close the known-component geometry for black METCASE UNICASE 1 **M5501119** and reduce the enclosure decision to evidence that genuinely remains unknown. Do not select arbitrary mains hardware or release drilling data.

## Manufacturer drawing evidence
The M5501119 drawing supplies the internal dimensions that G3-020 deliberately left open: **181.00 mm inside face-to-inside face, 161.01 mm internal floor dimension and 61.20 mm internal height**. The published base-PCB guide envelope remains 166 x 159 mm; component-fit work uses the larger physical internal envelope only where the drawing explicitly supports it.

## Known component overlay
- Toroid TI-69043-ME / TA030-15 conservative envelope: **78 x 78 x 36 mm**.
- Existing LM317/LM337 regulator module envelope: **75 x 85 x 31 mm**.
- Side-by-side rectangular overlay: **153 x 85 mm**.
- Residual internal floor before allocating mains-entry hardware or segregation zones: **28 mm lateral, 76.01 mm depth**.
- Both known component heights are below the 61.20 mm internal-height datum.

This is a conservative envelope proof, not a released placement. Transformer fastener geometry, wire exits, touch protection, creepage/clearance, service loops and thermal behaviour remain design constraints.

## Decision
**M5501119 is not rejected by the known transformer/regulator geometry, but remains RELEASE_BLOCKED rather than frozen.** Freezing it now would require inventing evidence that does not yet exist.

Only two release blockers remain for the PSU enclosure decision:
1. Select the exact filtered IEC/fuse/DPST-switch hardware and prove rear-panel depth, terminals, touch protection, mains/SELV segregation and wiring bend space.
2. Complete the passive thermal calculation/measurement for transformer plus LM317/LM337 dissipation in the closed 65 mm enclosure.

No arbitrary IEC inlet, fuse holder, switch, heatsink, hole position or drilling template is selected in G3-021.

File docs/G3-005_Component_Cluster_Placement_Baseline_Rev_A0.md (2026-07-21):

# G3-005 — Component-Cluster Placement Baseline Rev A0

## Purpose

Translate the accepted schematic and region architecture into a constrained
placement problem before any PCB coordinate is committed.

## Authority model

Sensitive analogue clusters are manual-authority. A placement engine may
propose their position and orientation, but the result is not accepted without
engineering review. The panel-control harness cluster may be synthesised under
constraints after connector pinouts are frozen.

## Coverage

Every on-board schematic reference is assigned to exactly one cluster. This is
regression-tested against the live block builders, preventing orphaned or
multiply-owned components as the design evolves.

## Deferred decisions

- enclosure part number;
- carrier-plate dimensions and fasteners;
- PCB outline and mounting holes;
- exact connector footprints and harness pinouts;
- exact XY coordinates and rotations.

These remain deferred deliberately rather than guessed.

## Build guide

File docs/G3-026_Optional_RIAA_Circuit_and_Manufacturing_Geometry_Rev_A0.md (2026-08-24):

# G3-026 — Optional-RIAA Circuit Realisation and Manufacturing-Control Geometry

**Revision:** A0  
**Status:** candidate  
**Base:** G3-025 / `89dfc9f8493ba6327d5ce175ccaaa75bb410dda4`

## 1. Primary objective

Convert the G3-025 transfer-function contract for the optional 3180 us term into
a practical, polarity-preserving stereo circuit; select the internal switch; close
the nominal upper-cover stack where evidence permits; and add automated regression
testing so future pushed branches can be inspected without manual console relay.

## 2. Topology trade

Three implementation classes were considered.

### A. Passive RC plus buffer — rejected

A simple 3180 us passive low-pass gives approximately 26 dB insertion loss at
1 kHz. Recovering that loss elsewhere couples the optional section into the gain
architecture and makes BYPASS level discontinuous.

### B. Inverting active low-pass — rejected

An inverting first-order active filter can use lower impedances and has attractive
noise/headroom characteristics, but ON would invert polarity while straight-through
BYPASS would not. Restoring common polarity requires another inversion path and
roughly doubles active circuitry.

### C. RC before non-inverting gain — selected

Each channel uses:
- 31.5 kΩ, 0.1% series timing resistor;
- 68 nF + 33 nF in parallel, both 1%, 50 V, C0G/NP0;
- one OPA1656 non-inverting stage;
- gain resistors 267 Ω / 5.08 kΩ, 0.1%.

Nominal timing is 3181.5 us (50.025 Hz). Nominal 1 kHz magnitude is +0.0049 dB.
Worst-corner 1 kHz level error from the stated R/C/gain tolerances is about
-0.11 to +0.12 dB.

The RC precedes the gain stage so out-of-band high-frequency energy is attenuated
before the approximately 20x amplifier. This improves internal overload behaviour
relative to placing the gain before the pole.

OPA1656 is already a controlled Shellac device in SCH101, so its reuse improves BOM,
qualification and stocking commonality. Its FET input is also well suited to the
31.5 kΩ timing source impedance.

## 3. Internal switch

Selected: **Nidec Components ASE2D-2M-10-Z**.

Required characteristics are satisfied:
- DPDT ON-ON;
- through-hole PC pins;
- gold contact finish;
- non-shorting / BBM timing;
- low-level 50 mA / 60 V class;
- compact internal/service configuration control.

The switch is placed at the section output. Each common feeds the downstream left or
right signal. One throw receives the straight-through `RIAA_CORE_OUT`; the other
receives the corresponding filtered/amplified `RIAA_3180_OUT`.

The optional filter remains driven in BYPASS, but disconnected from the downstream
signal. This keeps both switch throws low impedance and makes BYPASS genuinely
straight-through. Change this internal configuration with the unit muted or powered
down.

## 4. Timing capacitors

The frozen replay timing-capacitor rule is retained. G3-026 therefore does not use a
cheap X7R 100 nF part.

Selected parallel pair per channel:
- KEMET `C1206C683F5GECAUTO7210`, 68 nF, 1%, 50 V, C0G/NP0;
- KEMET `C1206C333F5GEC7210`, 33 nF, 1%, 50 V, C0G/NP0.

Total nominal capacitance is 101 nF. The small offset is compensated by selecting
31.5 kΩ, yielding 3181.5 us.

## 5. Headroom and noise

The realisation model retains the existing conservative 10 V RMS design-output
limit. The optional section permits more than 0.53 V RMS input at 20 Hz before
that limit.

For context, a 30 mV cartridge test input at the 22 dB SCH101 setting gives a
modelled optional-section output of roughly 7.0 V RMS at 20 Hz when combined with
the invariant 318/75 core, leaving useful margin to the 10 V RMS design limit.

The model also records a first-order 1 kHz white-noise proxy below 110 nV/√Hz.
This is a design-comparison metric, not a claim for final integrated system SNR;
SPICE/bench verification remains part of electrical release.

## 6. Upper-cover stack

The M5502119 manufacturer drawing marks 2.00 mm as a typical sheet dimension in the
cover/base detail. G3-026 accepts **2.0 mm nominal** for stack analysis but does not
invent a missing sheet-thickness tolerance.

Against that nominal:
- Grayhill bushing length 7.92 mm leaves 5.92 mm above the cover;
- C&K 7201SYCBE bushing length 8.89 mm leaves 6.89 mm above the cover.

This clears the basic “can the bushing reach through the cover?” concern. It does
**not** release drilling: final nut/washer/anti-rotation/knob stack, footprint Z,
manufacturer tolerance and PCB datum still require verification.

## 7. CI risk reduction

G3-026 adds a GitHub Actions workflow which:
- installs the repository requirements;
- compiles generator/tests;
- runs the complete pytest suite on `main`, `feature/**` pushes and pull requests.

Once merged, pushed work can be inspected via GitHub CI instead of relying solely
on manually relayed local pytest output.

## 8. Not released

G3-026 does not release:
- final SCH103 KiCad conversion of the optional section;
- external-control custom footprints;
- final PCB placement coordinates;
- top-cover drilling coordinates;
- enclosure machining;
- PCB fabrication.

## 9. Acceptance

- selected optional section is polarity-preserving and factor-consistent;
- nominal pole is within 0.1 Hz of 50 Hz;
- 1 kHz nominal level mismatch is under 0.01 dB;
- worst stated tolerance corner remains inside ±0.13 dB at 1 kHz;
- internal switch is exact-MPN, DPDT, gold, BBM and through-hole;
- nominal top-cover bushing penetration is modelled without inventing tolerance;
- CI workflow is present;
- focused and full regression suites pass.

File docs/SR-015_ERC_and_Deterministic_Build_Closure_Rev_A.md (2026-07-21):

# Project Shellac — SR-015 ERC and Deterministic Build Closure Rev A

## Status

Implemented and validated against the accepted SR-014 repository.

## Purpose

Close the remaining generated-project library, hierarchy attachment, electrical-rules and repeatability findings without changing any validated analogue value, gain target, replay curve, supply voltage or external control decision.

## Changes

- Generate project-local `Device`, `Connector_Generic` and `ProjectShellac` symbol libraries plus local symbol and footprint library tables.
- Correct the remaining connector, DIP-switch and ferrite-bead footprint identifiers.
- Attach every hierarchical interface to a real electrical endpoint or an explicit non-physical hierarchy anchor.
- Remove legacy local interface aliases in favour of Engineering Model signal names.
- Correct vertical two-pin connection routing and outward power-pin stubs that previously created unintended rail-name collisions.
- Mark the unused PSU connector pin with a KiCad no-connect marker.
- Add non-physical power-output declarations after the two PSU rail links so ERC can identify the regulated +18 V and -18 V rails as driven.
- Replace random child-sheet UUID generation and run-date title fields with deterministic values.
- Make the readiness audit consume native KiCad ERC evidence and pass only when the report is clean.

## Evidence

- Python regression suite: 122 passed.
- Engineering Model: 8 blocks, 27 signals, validation passed.
- Model-driven build: 8 implemented blocks, 0 pending.
- Root hierarchy: 8 sheets, 66 pins, 19 cross-sheet signals.
- CAD-ready functional sheets: 8/8.
- Native KiCad hierarchical ERC: 0 violations.
- Two consecutive clean builds: byte-identical generated project files.
- Gate 2 schematic readiness: PASS.

The accepted SR-014 baseline reported 286 native KiCad findings. SR-015 closes all of them through renderer, library and connectivity corrections. No analogue engineering decision was reopened.

## Programme consequence

Gate 2 is now passed by automated evidence. The next critical-path activity is a visual schematic capture review in KiCad, followed by any presentation-only corrections and then schematic freeze/ERC sign-off before PCB floor-planning and layout.

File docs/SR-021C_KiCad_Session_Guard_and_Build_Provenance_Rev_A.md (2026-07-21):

# SR-021C — KiCad Session Guard and Build Provenance

**Status:** process and generator-foundation correction  
**Electrical changes:** none

## Trigger

The submitted archive contained a live KiCad lock file. Its native ERC report
described root-sheet wire endpoints even though the included root schematic
contained no wires. A clean rebuild from the same source produced different
file hashes only because KiCad had rewritten line endings; semantically, the
source and generated files were identical.

The contradiction is consistent with ERC running against a stale in-memory
hierarchy while the generator updated the files on disk.

## Controls introduced

- hard failure if any generated KiCad lock file is present;
- SHA-256 hash inventory of every generated CAD file;
- deterministic Build ID;
- generated-project verification command;
- regression tests for open-session rejection and file-tamper detection.

These controls make native ERC evidence attributable to one known generated
build.

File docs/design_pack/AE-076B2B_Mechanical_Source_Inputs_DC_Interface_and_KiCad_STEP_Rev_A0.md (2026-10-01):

# AE-076B2B — Mechanical Source Inputs, DC Interface and KiCad STEP — Rev A0

**Parent baseline:** `1e8702139db68ef42bd0c2dd414db99524948309` (AE-076B2A)
**Status:** PARTIAL MCAD INPUT SET CONTROLLED — METCASE STEP INGESTED / GEOMETRY RECONCILIATION OPEN

The initial B2B transaction failed closed because METCASE requires registration
and login for 3D model downloads. This record therefore distinguishes public
manufacturer evidence from authenticated manufacturer geometry.

Controlled now:
- official M5502119 PDF drawing, hash-controlled;
- official Neutrik NC3FD-L-B-1, NC3MD-L-B-1, NC5MD-LX-B and NC5FD-LX-B STEP;
- governed KiCad PCB STEP export with source-board/version/hash evidence;
- five-pole Neutrik regulated-DC interface.

The authenticated M5502119 STEP is ingested and hash-controlled. Dimensional reconciliation against the controlled manufacturer drawing remains open.

J901 remains 1=0VA, 2=+17VA_IN, 3=-17VA_IN, 4=CHASSIS, 5=NC_RESERVED.
Selected DC hardware is NC5FD-LX-B at the PSU source, NC5MD-LX-B at the audio
chassis, with NC5MXX-B/NC5FXX-B cable ends.

Pin-1-to-shell bonding is prohibited. Generic 5-pole/DMX cable substitution is
prohibited unless pinout/continuity is verified.

The generated PCB STEP omits H901, C30060 and C35060 because their referenced 3D models are unavailable in the installed KiCad model set. FreeCAD assembly, exact PCB-model closure, NKK/C&K geometry, common-plane fit, six-support geometry, control XY and native migration remain open. Routing remains false.

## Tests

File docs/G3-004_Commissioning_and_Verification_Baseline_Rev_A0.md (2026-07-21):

# G3-004 — Commissioning and Verification Baseline Rev A0

G3-004 converts Rev A bring-up into ten gated stages from configuration control
through objective characterisation and controlled listening release.

Every stage records prerequisites, configuration, measurements, instruments,
limits, stop conditions and retained evidence.  Calculated expectations are
kept distinct from limits that require Rev A hardware characterisation.

The baseline is intentionally conservative: no stage may be bypassed after a
failure, listening cannot waive an objective defect, and mains/PE verification
is completed before the audio enclosure is connected.

Machine-readable output:

```
python scripts/report_commissioning_baseline.py
out/commissioning/commissioning_baseline.json
```

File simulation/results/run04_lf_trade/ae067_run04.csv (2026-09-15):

candidate | prior_disposition | lf_hard_pass | lf_preferred_pass | direct_20_db | direct_50_db | filter_f3_hz | filter_5_db | filter_10_db | filter_20_db | filter_30_db | filter_peak_db | direct_noise_uv_rms | filter_noise_uv_rms | direct_noise_delta_db_vs_branch_local | filter_noise_delta_db_vs_branch_local | switch_selector_peak_v | switch_objective_pass | direct_dc_step_settle_1pct_s
CURRENT_COMMON_PRE_SPLIT | REJECTED_BY_AE052_ANALYTICAL | False | False | -1.510435083655789 | -0.33096028531978905 | 17.36332736795352 | -41.45705077391451 | -17.00878097151451 | -1.9714130754645103 | -0.8712768346295097 | 0.0009792182083104683 | 0.5361209675049999 | 0.9718089680449999 | 0.03354781407887249 | 0.0990461691844021 | 0.00378824514337 | True | 2.16163539446
POST_SWITCH_COMMON | REJECTED_BY_AE052_TRANSIENT_RISK | True | True | -0.0025240680619588863 | -0.00040315930650963706 | 15.04858175115897 | -38.25606723730501 | -14.30323382460501 | -0.4635040927790104 | -0.04386217769691039 | 0.00010843598283846444 | 0.534054282503 | 0.960798946993 | 0.0 | 7.848759669477596e-05 | 0.249497413635 | False | 1.59224717298
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

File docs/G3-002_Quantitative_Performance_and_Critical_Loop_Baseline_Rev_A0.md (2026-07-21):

# G3-002 — Quantitative Performance and Critical-Loop Baseline

## Scope

- SCH101 selectable-gain budget at 5 mV RMS input.
- Validated and calculated design margins.
- Component criticality and substitution policies.
- Six measurable critical-loop placement constraints.
- Explicit register of quantities requiring later calculation or measurement.

## Key results

- Worst validated cartridge overload margin: 17.10 dB.
- SCH104 severe-signal margin to project ceiling: 9.87 dB.
- THAT1646 severe-output margin to project design ceiling: 3.85 dB.
- THAT1646 severe-output margin to datasheet capability: 8.95 dB.

Noise and distortion are not represented as falsely precise totals. They remain
open until cartridge source data, final component models and bench correlation
are available.

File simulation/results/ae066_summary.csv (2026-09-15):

RUN_ID | CASE_ID | METRIC | VALUE | UNIT | PASS_FAIL | NOTES
RUN01 | GRADO_78C_CABLE50_SERVICE0 | peak_below_20khz | 0.393655717 | dB | PASS | CHARACTERISATION
RUN01 | GRADO_78C_CABLE50_SERVICE0 | peak_below_50khz | 2.62124887 | dB | FAIL | CHARACTERISATION
RUN01 | GRADO_78C_CABLE50_SERVICE47 | peak_below_20khz | 0.690025645 | dB | PASS | CHARACTERISATION
RUN01 | GRADO_78C_CABLE50_SERVICE47 | peak_below_50khz | 4.97758834 | dB | FAIL | CHARACTERISATION
RUN01 | GRADO_78C_CABLE50_SERVICE100 | peak_below_20khz | 1.03601464 | dB | FAIL | CHARACTERISATION
RUN01 | GRADO_78C_CABLE50_SERVICE100 | peak_below_50khz | 7.91614655 | dB | FAIL | CHARACTERISATION
RUN01 | GRADO_78C_CABLE100_SERVICE0 | peak_below_20khz | 0.712166927 | dB | PASS | PRIMARY_NOMINAL_AUDIO_BAND_GATING_EXTENDED_BAND_OPEN
RUN01 | GRADO_78C_CABLE100_SERVICE0 | peak_below_50khz | 5.17699146 | dB | FAIL | PRIMARY_NOMINAL_AUDIO_BAND_GATING_EXTENDED_BAND_OPEN
RUN01 | GRADO_78C_CABLE100_SERVICE47 | peak_below_20khz | 1.01927289 | dB | FAIL | CHARACTERISATION
RUN01 | GRADO_78C_CABLE100_SERVICE47 | peak_below_50khz | 7.82771778 | dB | FAIL | CHARACTERISATION
RUN01 | GRADO_78C_CABLE100_SERVICE100 | peak_below_20khz | 1.378192 | dB | FAIL | CHARACTERISATION
RUN01 | GRADO_78C_CABLE100_SERVICE100 | peak_below_50khz | 9.64272743 | dB | FAIL | CHARACTERISATION
RUN01 | GRADO_78C_CABLE150_SERVICE0 | peak_below_20khz | 1.04223645 | dB | FAIL | CHARACTERISATION
RUN01 | GRADO_78C_CABLE150_SERVICE0 | peak_below_50khz | 8.03485045 | dB | FAIL | CHARACTERISATION
RUN01 | GRADO_78C_CABLE150_SERVICE47 | peak_below_20khz | 1.36083137 | dB | FAIL | CHARACTERISATION
RUN01 | GRADO_78C_CABLE150_SERVICE47 | peak_below_50khz | 9.66751217 | dB | FAIL | CHARACTERISATION
RUN01 | GRADO_78C_CABLE150_SERVICE100 | peak_below_20khz | 1.73361034 | dB | FAIL | CHARACTERISATION
RUN01 | GRADO_78C_CABLE150_SERVICE100 | peak_below_50khz | 10.324267 | dB | FAIL | CHARACTERISATION
RUN01 | GRADO_78C_CABLE200_SERVICE0 | peak_below_20khz | 1.38467632 | dB | FAIL | CHARACTERISATION
RUN01 | GRADO_78C_CABLE200_SERVICE0 | peak_below_50khz | 9.7560766 | dB | FAIL | CHARACTERISATION
RUN01 | GRADO_78C_CABLE200_SERVICE47 | peak_below_20khz | 1.71558743 | dB | FAIL | CHARACTERISATION
RUN01 | GRADO_78C_CABLE200_SERVICE47 | peak_below_50khz | 10.3533218 | dB | FAIL | CHARACTERISATION
RUN01 | GRADO_78C_CABLE200_SERVICE100 | peak_below_20khz | 2.1032488 | dB | FAIL | CHARACTERISATION
RUN01 | GRADO_78C_CABLE200_SERVICE100 | peak_below_50khz | 10.8580365 | dB | FAIL | CHARACTERISATION
RUN01 | GRADO_78C_CABLE300_SERVICE0 | peak_below_20khz | 2.11032582 | dB | FAIL | CHARACTERISATION
RUN01 | GRADO_78C_CABLE300_SERVICE0 | peak_below_50khz | 10.9356311 | dB | FAIL | CHARACTERISATION
RUN01 | GRADO_78C_CABLE300_SERVICE47 | peak_below_20khz | 2.46869094 | dB | FAIL | CHARACTERISATION
RUN01 | GRADO_78C_CABLE300_SERVICE47 | peak_below_50khz | 11.3052934 | dB | FAIL | CHARACTERISATION
RUN01 | GRADO_78C_CABLE300_SERVICE100 | peak_below_20khz | 2.88960677 | dB | FAIL | CHARACTERISATION
RUN01 | GRADO_78C_CABLE300_SERVICE100 | peak_below_50khz | 11.6539402 | dB | FAIL | CHARACTERISATION
RUN01 | AT_VM95SP_CABLE50_SERVICE0 | peak_below_20khz | 0.00870875236 | dB | PASS | CHARACTERISATION
RUN01 | AT_VM95SP_CABLE50_SERVICE0 | peak_below_50khz | 0.00870875236 | dB | PASS | CHARACTERISATION
RUN01 | AT_VM95SP_CABLE50_SERVICE47 | peak_below_20khz | 0.000126416826 | dB | PASS | PRIMARY_GATING_OFFICIAL_100_200PF
RUN01 | AT_VM95SP_CABLE50_SERVICE47 | peak_below_50khz | 0.000126416826 | dB | PASS | PRIMARY_GATING_OFFICIAL_100_200PF
RUN01 | AT_VM95SP_CABLE50_SERVICE100 | peak_below_20khz | 0.389684806 | dB | PASS | PRIMARY_GATING_OFFICIAL_100_200PF
RUN01 | AT_VM95SP_CABLE50_SERVICE100 | peak_below_50khz | 0.389684806 | dB | PASS | PRIMARY_GATING_OFFICIAL_100_200PF
RUN01 | AT_VM95SP_CABLE100_SERVICE0 | peak_below_20khz | 0.00176998948 | dB | PASS | PRIMARY_GATING_OFFICIAL_100_200PF
RUN01 | AT_VM95SP_CABLE100_SERVICE0 | peak_below_50khz | 0.00176998948 | dB | PASS | PRIMARY_GATING_OFFICIAL_100_200PF
RUN01 | AT_VM95SP_CABLE100_SERVICE47 | peak_below_20khz | 0.36255597 | dB | PASS | PRIMARY_GATING_OFFICIAL_100_200PF
RUN01 | AT_VM95SP_CABLE100_SERVICE47 | peak_below_50khz | 0.36255597 | dB | PASS | PRIMARY_GATING_OFFICIAL_100_200PF
RUN01 | AT_VM95SP_CABLE100_SERVICE100 | peak_below_20khz | 0.97083612 | dB | PASS | CHARACTERISATION
RUN01 | AT_VM95SP_CABLE100_SERVICE100 | peak_below_50khz | 0.97083612 | dB | PASS | CHARACTERISATION
RUN01 | AT_VM95SP_CABLE150_SERVICE0 | peak_below_20khz | 0.400752473 | dB | PASS | PRIMARY_GATING_OFFICIAL_100_200PF
RUN01 | AT_VM95SP_CABLE150_SERVICE0 | peak_below_50khz | 0.400752473 | dB | PASS | PRIMARY_GATING_OFFICIAL_100_200PF
RUN01 | AT_VM95SP_CABLE150_SERVICE47 | peak_below_20khz | 0.942874739 | dB | PASS | CHARACTERISATION
RUN01 | AT_VM95SP_CABLE150_SERVICE47 | peak_below_50khz | 0.942874739 | dB | PASS | CHARACTERISATION
RUN01 | AT_VM95SP_CABLE150_SERVICE100 | peak_below_20khz | 1.53517403 | dB | FAIL | CHARACTERISATION
RUN01 | AT_VM95SP_CABLE150_SERVICE100 | peak_below_50khz | 1.53517403 | dB | PASS | CHARACTERISATION
RUN01 | AT_VM95SP_CABLE200_SERVICE0 | peak_below_20khz | 0.983560478 | dB | PASS | CHARACTERISATION
RUN01 | AT_VM95SP_CABLE200_SERVICE0 | peak_below_50khz | 0.983560478 | dB | PASS | CHARACTERISATION
RUN01 | AT_VM95SP_CABLE200_SERVICE47 | peak_below_20khz | 1.50987207 | dB | FAIL | CHARACTERISATION
RUN01 | AT_VM95SP_CABLE200_SERVICE47 | peak_below_50khz | 1.50987207 | dB | PASS | CHARACTERISATION
RUN01 | AT_VM95SP_CABLE200_SERVICE100 | peak_below_20khz | 2.05084969 | dB | FAIL | CHARACTERISATION
RUN01 | AT_VM95SP_CABLE200_SERVICE100 | peak_below_50khz | 2.05084969 | dB | FAIL | CHARACTERISATION
RUN01 | AT_VM95SP_CABLE300_SERVICE0 | peak_below_20khz | 2.06228127 | dB | FAIL | CHARACTERISATION
RUN01 | AT_VM95SP_CABLE300_SERVICE0 | peak_below_50khz | 2.06228127 | dB | FAIL | CHARACTERISATION
RUN01 | AT_VM95SP_CABLE300_SERVICE47 | peak_below_20khz | 2.49710331 | dB | FAIL | CHARACTERISATION
RUN01 | AT_VM95SP_CABLE300_SERVICE47 | peak_below_50khz | 2.49710331 | dB | FAIL | CHARACTERISATION
RUN01 | AT_VM95SP_CABLE300_SERVICE100 | peak_below_20khz | 2.93650606 | dB | FAIL | CHARACTERISATION
RUN01 | AT_VM95SP_CABLE300_SERVICE100 | peak_below_50khz | 2.93650606 | dB | FAIL | CHARACTERISATION
RUN01 | GRADO_GOLD_8MZ_CABLE50_SERVICE0 | peak_below_20khz | 0.426356417 | dB | PASS | COMPATIBILITY_NON_GATING
RUN01 | GRADO_GOLD_8MZ_CABLE50_SERVICE0 | peak_below_50khz | 2.80563288 | dB | FAIL | COMPATIBILITY_NON_GATING
RUN01 | GRADO_GOLD_8MZ_CABLE50_SERVICE47 | peak_below_20khz | 0.75389117 | dB | PASS | COMPATIBILITY_NON_GATING
RUN01 | GRADO_GOLD_8MZ_CABLE50_SERVICE47 | peak_below_50khz | 5.32431927 | dB | FAIL | COMPATIBILITY_NON_GATING
RUN01 | GRADO_GOLD_8MZ_CABLE50_SERVICE100 | peak_below_20khz | 1.13734046 | dB | FAIL | COMPATIBILITY_NON_GATING
RUN01 | GRADO_GOLD_8MZ_CABLE50_SERVICE100 | peak_below_50khz | 8.00260283 | dB | FAIL | COMPATIBILITY_NON_GATING
RUN01 | GRADO_GOLD_8MZ_CABLE100_SERVICE0 | peak_below_20khz | 0.778431868 | dB | PASS | COMPATIBILITY_NON_GATING
RUN01 | GRADO_GOLD_8MZ_CABLE100_SERVICE0 | peak_below_50khz | 5.53428273 | dB | FAIL | COMPATIBILITY_NON_GATING
RUN01 | GRADO_GOLD_8MZ_CABLE100_SERVICE47 | peak_below_20khz | 1.11883927 | dB | FAIL | COMPATIBILITY_NON_GATING
RUN01 | GRADO_GOLD_8MZ_CABLE100_SERVICE47 | peak_below_50khz | 7.96688568 | dB | FAIL | COMPATIBILITY_NON_GATING
RUN01 | GRADO_GOLD_8MZ_CABLE100_SERVICE100 | peak_below_20khz | 1.51783637 | dB | FAIL | COMPATIBILITY_NON_GATING
RUN01 | GRADO_GOLD_8MZ_CABLE100_SERVICE100 | peak_below_50khz | 9.00731301 | dB | FAIL | COMPATIBILITY_NON_GATING
RUN01 | GRADO_GOLD_8MZ_CABLE150_SERVICE0 | peak_below_20khz | 1.14437107 | dB | FAIL | COMPATIBILITY_NON_GATING
RUN01 | GRADO_GOLD_8MZ_CABLE150_SERVICE0 | peak_below_50khz | 8.12695137 | dB | FAIL | COMPATIBILITY_NON_GATING
RUN01 | GRADO_GOLD_8MZ_CABLE150_SERVICE47 | peak_below_20khz | 1.49859848 | dB | FAIL | COMPATIBILITY_NON_GATING
RUN01 | GRADO_GOLD_8MZ_CABLE150_SERVICE47 | peak_below_50khz | 9.04118652 | dB | FAIL | COMPATIBILITY_NON_GATING
RUN01 | GRADO_GOLD_8MZ_CABLE150_SERVICE100 | peak_below_20khz | 1.91430895 | dB | FAIL | COMPATIBILITY_NON_GATING
RUN01 | GRADO_GOLD_8MZ_CABLE150_SERVICE100 | peak_below_50khz | 9.64230156 | dB | FAIL | COMPATIBILITY_NON_GATING
RUN01 | GRADO_GOLD_8MZ_CABLE200_SERVICE0 | peak_below_20khz | 1.52519627 | dB | FAIL | COMPATIBILITY_NON_GATING
RUN01 | GRADO_GOLD_8MZ_CABLE200_SERVICE0 | peak_below_50khz | 9.10558472 | dB | FAIL | COMPATIBILITY_NON_GATING
RUN01 | GRADO_GOLD_8MZ_CABLE200_SERVICE47 | peak_below_20khz | 1.89428159 | dB | FAIL | COMPATIBILITY_NON_GATING
RUN01 | GRADO_GOLD_8MZ_CABLE200_SERVICE47 | peak_below_50khz | 9.6679637 | dB | FAIL | COMPATIBILITY_NON_GATING
RUN01 | GRADO_GOLD_8MZ_CABLE200_SERVICE100 | peak_below_20khz | 2.32798011 | dB | FAIL | COMPATIBILITY_NON_GATING
RUN01 | GRADO_GOLD_8MZ_CABLE200_SERVICE100 | peak_below_50khz | 10.1535354 | dB | FAIL | COMPATIBILITY_NON_GATING
RUN01 | GRADO_GOLD_8MZ_CABLE300_SERVICE0 | peak_below_20khz | 2.33609076 | dB | FAIL | COMPATIBILITY_NON_GATING
RUN01 | GRADO_GOLD_8MZ_CABLE300_SERVICE0 | peak_below_50khz | 10.2194247 | dB | FAIL | COMPATIBILITY_NON_GATING
RUN01 | GRADO_GOLD_8MZ_CABLE300_SERVICE47 | peak_below_20khz | 2.7384013 | dB | FAIL | COMPATIBILITY_NON_GATING
RUN01 | GRADO_GOLD_8MZ_CABLE300_SERVICE47 | peak_below_50khz | 10.5693746 | dB | FAIL | COMPATIBILITY_NON_GATING
RUN01 | GRADO_GOLD_8MZ_CABLE300_SERVICE100 | peak_below_20khz | 3.21236361 | dB | FAIL | COMPATIBILITY_NON_GATING
RUN01 | GRADO_GOLD_8MZ_CABLE300_SERVICE100 | peak_below_50khz | 10.8725034 | dB | FAIL | COMPATIBILITY_NON_GATING
RUN02 | LOW | gain_1khz | 13.9371881 | dB | PASS
RUN02 | LOW | cmrr_20khz | 96.080055 | dB | PASS
RUN02 | DEFAULT | gain_1khz | 18.0208942 | dB | PASS
RUN02 | DEFAULT | cmrr_20khz | 96.080055 | dB | PASS
RUN02 | HIGH | gain_1khz | 21.9779594 | dB | PASS
RUN02 | HIGH | cmrr_20khz | 96.080055 | dB | PASS
RUN03 | FLAT__FLAT | model_correlation_max_error | 4.058084e-05 | dB | PASS | NAMED_HISTORICAL
RUN03 | FLAT__FLAT | target_max_error | 2.279749e-05 | dB | PASS | FLAT
RUN03 | FLAT__1600_Hz | model_correlation_max_error | 0.00111791066 | dB | PASS | UNNAMED_ADJUSTMENT
RUN03 | FLAT__2121_Hz_RIAA | model_correlation_max_error | 0.00104994613 | dB | PASS | UNNAMED_ADJUSTMENT
RUN03 | FLAT__3400_Hz | model_correlation_max_error | 0.000856255444 | dB | PASS | UNNAMED_ADJUSTMENT
RUN03 | FLAT__5800_Hz | model_correlation_max_error | 0.000494701112 | dB | PASS | UNNAMED_ADJUSTMENT
RUN03 | 200_Hz__FLAT | model_correlation_max_error | 0.00084327868 | dB | PASS | NAMED_HISTORICAL
RUN03 | 200_Hz__FLAT | target_max_error | 0.0114581668 | dB | PASS | 78-200-FLAT
RUN03 | 200_Hz__1600_Hz | model_correlation_max_error | 0.00108052593 | dB | PASS | NAMED_HISTORICAL
RUN03 | 200_Hz__1600_Hz | target_max_error | 0.0308332898 | dB | PASS | 78-200-1600
RUN03 | 200_Hz__2121_Hz_RIAA | model_correlation_max_error | 0.00101854424 | dB | PASS | UNNAMED_ADJUSTMENT
RUN03 | 200_Hz__3400_Hz | model_correlation_max_error | 0.00087843477 | dB | PASS | NAMED_HISTORICAL
RUN03 | 200_Hz__3400_Hz | target_max_error | 0.0272451338 | dB | PASS | 78-200-3400
RUN03 | 200_Hz__5800_Hz | model_correlation_max_error | 0.000859122588 | dB | PASS | NAMED_HISTORICAL
RUN03 | 200_Hz__5800_Hz | target_max_error | 0.0113590701 | dB | PASS | 78-200-5800
RUN03 | 400_Hz__FLAT | model_correlation_max_error | 0.000895053735 | dB | PASS | NAMED_HISTORICAL
RUN03 | 400_Hz__FLAT | target_max_error | 0.00718410868 | dB | PASS | 78-400-FLAT
RUN03 | 400_Hz__1600_Hz | model_correlation_max_error | 0.000993916192 | dB | PASS | NAMED_HISTORICAL
RUN03 | 400_Hz__1600_Hz | target_max_error | 0.0292039157 | dB | PASS | 78-400-1600
RUN03 | 400_Hz__2121_Hz_RIAA | model_correlation_max_error | 0.00094106093 | dB | PASS | UNNAMED_ADJUSTMENT
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

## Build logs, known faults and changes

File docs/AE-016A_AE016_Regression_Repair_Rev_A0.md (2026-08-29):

# AE-016A — AE-016 Regression Repair

AE-016 caused broad regressions by replacing the authoritative central SCH101
model before the LT5400 CAD implementation and dependent tests had been migrated.

The existing suite explicitly freezes the active converter at 3.48x. That test
is valid for the current physical generator baseline and must not simply be
weakened.

AE-016A therefore:
- restores `generator/model/balanced_input.py` exactly to the pre-AE016 baseline;
- retains DR-038 as SELECTED, but stages it for an atomic CAD/test migration;
- retains DR-039 as the implementable independent change;
- removes the AE016 patch to `signal_chain_analysis.py` from the apply process;
- makes the SCH103 DR-039 patch idempotent.

After AE-016A the active SCH101 generator should again satisfy the historical
regression suite, while the 4x precision candidate remains preserved in
`sch101_precision_candidate.py` for the next controlled migration.

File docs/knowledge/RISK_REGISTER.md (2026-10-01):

# Project Shellac — Risk and Open-Item Register

| ID | Item | State | Closure |
|---|---|---|---|
| R-001 | Older panel/off-board control representation conflicts with PCB-established control-stack intent | MITIGATED_AE076B_MCAD_OPEN | AE-076B selects one main audio PCB carrying all seven controls directly as part of the removable upper-cover service module. AE-075D/E/F local-board/harness architecture is historical provenance. Exact MCAD Z/XY/support/footprint migration remains under B03. |
| R-002 | Bass/Treble rotary exact production MPNs not frozen | RESOLVED_PART_SELECTION / B03_PHYSICAL_IMPLEMENTATION_OPEN | AE-075C freezes NKK NR01105ANG13-2C/-2A; AE-076B reconciles live mechanical evidence to the no-threaded-bushing AT3009 12.3 mm installation and selects direct main-PCB ownership. Exact footprint/XY and MCAD support stack remain open. |
| R-003 | Exact Channel Mode implementation | RESOLVED_ARCHITECTURE / QUALIFICATION_OPEN | AE-041 A1 selects C&K A30403RNCB 3P4T BBM gold THT, TE/Alcoswitch MRJE3404 fallback. AE-068 RUN05 qualifies steady-state routing, direct insertion, mono weighting and stereo crosstalk through a conservative 5 pF lumped parasitic bracket; 10 pF still meets the AE-049 20 kHz minimum. RUN12 BBM transient qualification plus production sample continuity/detent mapping, exact parasitic correlation and bench verification remain before manufacturing release. |
| R-004 | Rumble/Mute toggle MPNs not frozen | RESOLVED | Common C&K 7201SYCBE selected. |
| R-005 | Rail LED physical implementation/MPNs not frozen | RESOLVED | Vishay TLLG4401 + A104700BLACK; audio top-cover centre spine. |
| R-006 | Manufacturing mounting-hole authority absent from current review board | INTERIM_SR040_AE071B_GEOMETRY_MCAD_MIGRATION_OPEN | SR-040/AE-071B MH1-MH4 remain locked as interim physical CAD; AE-076B selects six PCB-to-upper-cover supports. No hole is moved/added until AE-076B2 MCAD freezes support XY/Z/tolerances. |
| R-007 | Final drilling coordinates/templates intentionally gated | DEFERRED | Release after verified controls/PCB datums and REG-08 registration closure. |
| R-008 | Closed-box PSU temperature not analytically predicted from controlled load/Rth data | VERIFY_ON_PROTOTYPE | First powered prototype. |
| R-009 | Historical BOM/design rationale previously lived partly outside Git | ACTIVE_MITIGATION | Controlled registers/BOM updated with each decision lock. |
| R-010 | Separate later RIAA ON/BYPASS architecture conflicted with the complete SCH103 branch | RESOLVED / SUPERSEDED | DR-037 restores complete RIAA in SCH103 and removes the independent downstream 3180 us stage. |
| R-011 | Old BOM mute-relay entry conflicts with selected mechanical input mute | RESOLVED | SW905 mechanical DPDT input mute immediately before THAT1646; no relay/timer/comparator architecture. |
| R-012 | Selected external switch MPNs lack final controlled PCB footprints/3D envelopes | PARTIALLY_MITIGATED_AE076B_MCAD_OPEN | AE-076B selects all seven controls directly on the single main audio PCB and removes local control-PCB/inter-board-harness ownership. AE-076B2 must close C&K/NKK stack, six-support geometry, exact footprints/3D envelopes, control XY/apertures and physical CAD migration before routing. |
| R-013 | Engineering method/decision hierarchy existed only implicitly across knowledge files and conversation | RESOLVED | FDR-001 and controlled authority structure established. |
| R-014 | Regression evidence depended on manual local console relay | MITIGATED | Automated compile/full-pytest workflow exists; release still requires clean-clone/current regression evidence. |
| R-015 | Legacy TRUE RIAA branch duplicates an independent 3180 us stage | CLOSED_SUPERSEDED | DR-037 explicitly removes the independent 3180 us stage. Complete RIAA remains in SCH103. |
| R-016 | Controlled BOM is not procurement-complete | ACTIVE_MITIGATION | Complete after SPICE sensitivity/value engineering, cross-design rationalisation and landed-cost optimisation. |
| R-017 | Replay-configuration key could diverge from controlled electrical replay model | OPEN | Generate final legend/content from the controlled replay-curve data; all 25 Bass x Treble combinations remain intentional adjustment states. |
| R-018 | DR-039/SCH107 LF coupling architecture not yet simulation-qualified | MITIGATED_PRODUCT_MIGRATED_QUALIFICATION_OPEN | AE-067 RUN04 selects and qualifies the branch-local topology at nominal subsystem level; AE-074 migrates the stable C30060/R30060/C35060/R35060 identities into the SCH107 DIRECT/BYPASS branches and removes the common SCH103 block. AE-074 native-PCB F8/net/metadata reconciliation is complete; RUN09 noise, RUN10 sensitivity/tolerance, RUN12 full switching and bench correlation remain open. |
| R-019 | SCH101 precision front-end qualification remains incomplete | MITIGATED_PRODUCT_MIGRATED_QUALIFICATION_OPEN | AE-071A migrates the AE-042 topology. AE-075B selects LT5400BIMS8E-7#PBF, bonds EP9 to quiet 0VA, and selects compatible Samtec TSW/MNT hardware. RUN10 complete-stage tolerance/CMRR and 20 kHz parasitic acceptance remain open; Samtec physical pairing/orientation, short-route parasitic verification and bench qualification remain open. |
| R-020 | Output phantom-power clamps can inject fault energy into nominal ±17 V rails whose regulators are not demonstrated current sinks | OPEN_SYSTEM_QUALIFICATION | AE-076A changes current rail authority to ±17 V but does not close fault-energy behaviour. Full non-ideal phantom fault simulation and powered/unpowered bench verification remain required under RUN14 before baseline. |
| R-021 | Primary cartridge return/body isolation not fully established from manufacturer documentation | VERIFY_ON_BENCH | Measure AT-VM95SP and Grado Prestige 78C coil/return/body continuity before prototype qualification; model actual topology. AE-064 deliberately does not close this bench obligation. |
| R-022 | 0VA-to-CHASSIS alternative components can create redundant population in direct-bond build | MITIGATED / CONFIGURATION_OPEN | With R909=0 Ohm selected, C909 is DNP; D901/D902 remain DNP. Final grounding/hum/EMC choice requires prototype evidence. |
| R-023 | Historical/current authority registers can lag live implementation authority | MITIGATED_BY_RECONCILIATION | AE-076B explicitly supersedes current AE-075D/E/F ownership semantics while preserving those records and SR-040/AE-071B as historical/interim physical evidence until MCAD migration. |
| R-024 | Integrated full-system LTspice qualification remains incomplete | OPEN_SYSTEM_QUALIFICATION | AE-065 completes genuine RUN00; AE-066 qualifies RUN01-RUN03; AE-067 completes RUN04; AE-068 qualifies RUN05 steady-state matrix behaviour; AE-069 completes reproducible RUN06 SCH108 simulation evidence; AE-070 qualifies RUN07 representative nominal end-to-end AC behaviour and retains its historical qualification boundary. AE-076A adds current ±17 V integrated RUN00 sanity plus targeted SCH108/PRE90 rail/headroom requalification without rewriting those records. RUN06 prototype load/cable stability and dynamic THD remain bench gates; RUN08-RUN14, the Grado extended-band finding and final bench correlation remain open. |
| R-025 | Configuration-control semantics can drift from live-versus-selected-next implementation | MITIGATED_BY_AE059_AE071A_AE074 | AE-059 aligns status vocabulary and authority semantics; AE-071A migrates AE-042 SCH101 atomically and AE-074 separately migrates the AE-067 selected DR-039 topology while preserving AE-067 as qualification evidence. AE-068/069/070 retain their stated qualification boundaries. |
| R-026 | Integrated SHELLAC_TOP model not yet implemented; current RUN00 is toolchain-only | MITIGATED_INTEGRATED_RUN00_BY_AE065 | AE-065 implements the selected-next SHELLAC_TOP candidate-analysis model and passes the genuine nominal integrated RUN00 structural/DC sanity gate. Full deterministic RUN01-RUN14 qualification remains open under R-024; no product-generator migration is implied. |
| R-027 | Controlled SPICE model-source ingestion and wrapper qualification incomplete | MITIGATED_MODEL_SOURCE_GATE_CLOSED_BY_AE064 | AE-062 qualifies OPA1656, OPA1612, LT5400-7 and THAT1646; AE-063 qualifies S1G; AE-064 qualifies the required Grado 78C and AT-VM95SP behavioural electrical source models. Static RESOLVED labels are cross-checked against qualification evidence. |
| R-028 | SCH108 clamp identity/model provenance was inconsistent with the live SMA implementation | PARTIALLY_MITIGATED_BY_AE063 | AE-063 reconciles active SCH108 to Vishay S1G (1 A / 400 V, SMA/DO-214AC) and controls the manufacturer SPICE reference hash/execution. System pulse-energy, rail-injection, powered/unpowered survival and final procurement-suffix equivalence remain open under R-020 and AE-049/050. |
| R-029 | SCH108 output ferrite final selection remains open | PARTIALLY_MITIGATED_BY_AE069_AE075A_AE075G | AE-069 controls official Murata BLM21PG600SN1 / BLM21PG221SN1 small-signal models and completes exact-topology HF AC evidence. AE-075A separately closes the Panasonic ECEA1VN100U 10 uF bipolar sense-cap body/footprint reconciliation. AE-075G validates the exact output harness interface and 2 kOhm application load. Final ferrite selection remains pending EMC/layout/prototype correlation; RUN06 load/cable stability and dynamic THD remain bench gates. |
| R-030 | SCH103 timing-capacitor sourcing may not support every current 50 V / 1% / C0G / assumed-package decomposition economically | OPEN_COMPONENT_SOURCE_RECONCILIATION | AE-066 verifies several large-value 50 V / 1% C0G parts but does not identify a current 120 nF 1206 50 V 1% part in the searched UK channels; 27 nF 1206 50 V is readily found at 5%. A 100 nF + 33 nF 1% C0G candidate is staged for the 1600 Hz position because it is sourceable and analytically closer to target, but no replay-network change is authorised before RUN10/value-engineering and procurement review. |
| R-031 | SCH101 removable service-shunt production pairing/orientation and ganged cartridge-load header parasitic/layout behaviour are not physically verified | OPEN_ROUTING_BLOCKER | Verify MNT-104/MNT-102 continuity and orientation against production samples/drawings; correlate H110-H122 pad mapping, keep cartridge-load runs short/symmetric, and accept parasitic/layout impact before final routing. |
| R-032 | PRE90 application high-level margin is small in the worst Shellac high-gain representative state | LOAD_COMPATIBILITY_PASS_HIGH_LEVEL_BENCH_OPEN | AE-076A requalifies the output stage at ±17 V. Worst 2 kOhm insertion loss is 0.209239 dB; maximum high-gain PRE90 output is 9.071872 Vrms with 0.2157 dB minimum margin to the published 9.3 Vrms input-sensitivity figure. Electrical compatibility passes, but actual PRE90 operating/gain-state and clean high-level bench confirmation remain mandatory. |
| R-033 | Intended ±17 V product authority had drifted from live ±18 V implementation/simulation/CAD contracts | RESOLVED_BY_AE076A | AE-076A migrates the live generator, power/harness identities, current RUN00 contract, commissioning expectations and governed PCB net names to +17 V / 0VA / -17 V; adds fresh ±17 V integrated and SCH108/PRE90 evidence; and preserves historical ±18 V records unchanged. Powered PSU qualification remains separately open. |
| R-034 | Selected one-main-PCB upper-cover service-module architecture lacks a dimensionally controlled full-chassis digital mock-up | OPEN_PCB_3D_MODEL_AND_ASSEMBLY_GATE | AE-076B2B controls the official enclosure drawing, authenticated M5502119 STEP, Neutrik panel CAD and governed PCB STEP. M5502119 STEP-to-drawing reconciliation plus H901/C30060/C35060 PCB 3D-model closure, NKK/C&K plane fit, six-support geometry and full assembly/service review remain open. |
| R-035 | Five-pole XLR regulated-DC interface can mate with unrelated 5-pole XLR/DMX infrastructure | OPEN_MIS_MATING_CONTROL | Controlled Shellac cable, explicit `SHELLAC +/-17 V DC ONLY` labelling; prohibit generic substitution without continuity/pinout verification. |
| R-036 | Neutrik DLX optional pin-1-to-shell link could bypass R909 grounding authority | CONTROLLED_PROHIBITION_VERIFY_ON_BUILD | Do not fit optional pin1-shell bond. Pin1=0VA; pin4/shell=CHASSIS; verify isolation at commissioning. |
| R-037 | Governed KiCad STEP export omits H901, C30060 and C35060 because their referenced STEP models are unavailable in the installed KiCad 9 model set | OPEN_MCAD_MODEL_CLOSURE | Do not treat the PCB STEP as complete mechanical authority. Resolve exact H901 and C30060/C35060 3D bodies/references and regenerate before full interference/clearance acceptance. |

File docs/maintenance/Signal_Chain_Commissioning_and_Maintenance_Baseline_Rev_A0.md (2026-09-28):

# Project Shellac — Signal-Chain Commissioning and Maintenance Baseline

**Status:** PRE-PRODUCTION MAINTENANCE BASELINE  
**Evidence:** DR-037, DR-038, DR-039, AE-012 through AE-023, AE-066, AE-067, AE-074, AE-075A, AE-075B

## Normal configuration

- SCH101 gain: DEFAULT / approximately 18 dB.
- HIGH gain is reserved for lower-output cartridges and has reduced low-frequency headroom.
- Rumble filter may be FILTER or BYPASS; AE-074 DR-039 provides branch-local DC isolation in BYPASS, while SCH107's high-pass capacitors provide intrinsic DC isolation in FILTER.
- Full RIAA replay uses TRUE RIAA 3180/318 us bass plus 2121 Hz treble.

## Power sequencing

The DR-039 DIRECT/BYPASS 1 µF / 330 kΩ network has a time constant of approximately 0.33 s.

For commissioning and conservative operation:

1. engage MUTE before applying or removing power;
2. apply power;
3. allow at least 2 s before releasing MUTE;
4. before power-down, engage MUTE first.

Two seconds corresponds to more than six DR-039 DIRECT/BYPASS time constants
and leaves less than 0.3% of an initial direct-branch DC-block charging
transient. FILTER has its own SCH107 high-pass dynamics; RUN12 and prototype
evidence retain authority for final switching/transient acceptance.

This is an operating/commissioning recommendation, not an automatic timing
function; Shellac retains its mechanical mute philosophy.

## Expected nominal level

At DEFAULT gain with a 5 mV RMS cartridge reference and complete RIAA, the
balanced XLR output around 1 kHz is approximately 0.65 V RMS differential.

## Headroom

The conservative Shellac design ceiling remains 10 V RMS differential.

- DEFAULT retains useful wanted-band headroom at the 5 mV reference.
- HIGH is valid but is a lower-output-cartridge sensitivity setting and should
  not be used merely to obtain a louder output.

## CMRR commissioning targets

With a symmetrical low-impedance test source:

- >=70 dB, 20 Hz to 1 kHz, at LOW/DEFAULT/HIGH;
- >=60 dB at 20 kHz.

AE-066 RUN02 establishes the nominal gain/CMRR evidence. AE-075B selects
LT5400BIMS8E-7#PBF and bonds EP9 to quiet 0VA; RUN10 still owns complete-stage
tolerance/mismatch qualification for RF-series, service-gain, LT5400 ratio
errors and 20 kHz parasitic behaviour. The historical AE-023 A-grade tolerance
model is not current production acceptance authority.

## DC offset

With AE-074 fitted, upstream SCH101/SCH103 static offset is blocked by DR-039
in the DIRECT/BYPASS branch and by the intrinsic SCH107 high-pass capacitors in
the FILTER branch.

A conservative analytical downstream differential DC limit is approximately
20 mV. A tighter measured production acceptance value should be frozen after
prototype data exists.

## Electronics noise

The current first-order complete-RIAA electronics model predicts an output
noise of order 0.1 mV RMS and electronics SNR in the mid-70 dB range against
the nominal output. 78-rpm record/surface noise will normally dominate.

## Service caution

Do not substitute an ordinary DIP switch into the SCH101 precision feedback
path. One four-gang removable gold shunt configures all gain legs together:
LOW bridges the 332 ohm RF-parallel branches, HIGH bridges the 866 ohm
RG-parallel branches, and DEFAULT leaves both active branches open with the
shunt parked. AE-075B selects Samtec TSW-104-07-G-D/MNT-104-BK-G for gain and
TSW-102-07-G-D/MNT-102-BK-G for loading. Verify production shunt
pairing/orientation before relying on silkscreen position and retain the
short/symmetric routing-parasitic check. A separate two-gang shunt selects
BASE/+47/+100 pF cartridge loading.

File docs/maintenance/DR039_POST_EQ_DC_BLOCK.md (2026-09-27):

# DR-039 maintenance note

AE-074 implements DR-039 as a branch-local network inside SCH107. In each DIRECT/BYPASS branch, a 1 µF PET-film capacitor is followed by a 330 kΩ / 1% return to 0VA. The FILTER branch does not use this extra network because the SCH107 high-pass capacitors already provide intrinsic DC blocking.

The direct-branch nominal time constant is approximately 0.33 s; about 2 s is more than six direct-branch time constants. This does not replace RUN12 or prototype transient qualification.

Stable physical identities are retained: C30060/R30060 (left) and C35060/R35060 (right). After replacement verify the relevant DIRECT/BYPASS branch DC behaviour, FILTER/BYPASS operation, and replay response at 20 Hz.

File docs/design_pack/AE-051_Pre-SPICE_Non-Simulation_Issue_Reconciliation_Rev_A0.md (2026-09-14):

# AE-051 — Pre-SPICE Non-Simulation Issue Reconciliation
**Project:** Shellac
**Status:** INTERIM / PRE-SPICE CONFIGURATION RECONCILIATION
**Date:** 2026-09-11

## Purpose
Close or correctly classify outstanding issues that do not require SPICE evidence before the simulation campaign begins.

---

## 1. Control-authority conflict

### Finding
AE-040B is superseded by later controlled authority.

AE-040B still states:
- linked-stereo 2P5 Bass/Treble;
- Lorlin PT preferred;
- 4P4 Channel Mode concept.

AE-041 A1 and the live generator/BOM now state:
- four independent Bass/Treble controls, one per channel;
- NKK NR01 family for EQ controls;
- 3P4T C&K A30403RNCB matrix, TE MRJE3404 fallback;
- front-to-rear top-cover sequence retained.

### Disposition
**CLOSED AT ARCHITECTURE LEVEL.**

Current authority:
- AE-041 A1 + live generator/model/control_architecture.py + controlled BOM.

AE-040B shall remain historical provenance and shall not be used for procurement or manufacturing release.

### EQ rotary exact MPN
The NR01 electrical requirement is:
- SP5T;
- 5 fixed positions;
- BBM / non-shorting;
- gold contacts;
- straight PCB terminals;
- quantity one procurement.

NKK NR01105ANG13 satisfies those electrical requirements and is available as a no-knob base variant.

However:
- the final panel/PCB stack;
- usable actuator projection;
- external knob retention;
- final chosen knurled-knob compatibility;
- final drilling/registration

remain mechanical release items.

Therefore the exact production EQ rotary MPN remains:
**FAMILY SELECTED / EXACT MPN OPEN.**

Do not prematurely freeze NR01105ANG13 until the top-cover stack is mechanically checked.

---

## 2. AT-VM95SP balanced-input compatibility

### Published evidence
Audio-Technica documentation identifies four output terminals:
- white: left +
- blue: left -
- red: right +
- green: right -

Published electrical data:
- output 2.7 mV at 1 kHz, 5 cm/s;
- DC resistance 485 Ohm;
- inductance 550 mH;
- recommended load 47 kOhm;
- recommended capacitance 100–200 pF.

This is strongly consistent with use as a floating two-channel source into Shellac's differential left/right inputs.

### Remaining evidence gap
The manufacturer documentation located does not explicitly guarantee:
- infinite DC resistance between L- and R-;
- no internal connection from either return to cartridge body/shield.

### Disposition
**PRIMARY QUALIFICATION CARTRIDGE — ELECTRICALLY COMPATIBLE SUBJECT TO BENCH CONTINUITY CHECK.**

Before prototype qualification:
1. measure L+ to L-;
2. measure R+ to R-;
3. measure L- to R-;
4. measure every terminal to cartridge body;
5. record values.

Acceptance for Shellac balanced use:
- each coil measures plausibly close to published DC resistance;
- no unintended low-resistance L-/R- common;
- no low-resistance terminal-to-body bond.

If returns are internally common, Shellac may still operate electrically but it is no longer a fully floating differential-source qualification case and shall be modelled/documented accordingly.

---

## 3. Grado 78E compatibility

### Published evidence
Current third-party product data consistently identifies the legacy Grado 78E as approximately:
- 5 mV output;
- 475 Ohm resistance;
- 45 mH inductance;
- 47 kOhm load;
- 78-rpm cartridge.

Current Grado public product pages no longer expose a detailed 78E product record, so manufacturer-level evidence for terminal topology was not located.

The cartridge is frequently described as "mono", but that label alone does not establish whether:
- the body contains two independent coils;
- the returns are internally common;
- channels are strapped internally;
- only the stylus/generator response is mono.

### Disposition
**PRIMARY 78-RPM INTENT RETAINED / BALANCED TERMINAL TOPOLOGY REQUIRES BENCH CONFIRMATION.**

Required continuity check:
1. identify all four cartridge terminals;
2. L+ to L-;
3. R+ to R-;
4. L- to R-;
5. L+ to R+;
6. each terminal to body.

Do not assume the older Grado 78C/78E proxy is a fully floating stereo electrical model until measured.

---

## 4. 0VA-to-CHASSIS network

Live SCH106 fits:
- R909 = 0 Ohm direct 0VA-to-CHASSIS bond;
- C909 = 100 nF in parallel;
- D901/D902 opposed clamps DNP.

### Finding
With R909 = 0 Ohm fitted, C909 is electrically bypassed by the direct bond.

### Disposition
- R909: **RETAIN PROVISIONALLY**
- C909: **DNP IN DIRECT-BOND BUILD**
- D901/D902: **DNP**
- direct-bond versus alternative lift configuration: final bench/hum/EMC evidence item.

The C909 footprint may remain only as an explicit alternative-configuration provision. It should not be populated in the selected direct-bond configuration.

---

## 5. Controlled-register staleness

### Risk Register
The current Risk Register is materially stale:
- R-002 incorrectly says Grayhill Bass/Treble is selected;
- R-003 incorrectly says Grayhill 4P4 Channel Mode is selected;
- R-015 still treats duplicate RIAA as open-blocking although DR-037 superseded it.

### Current decision index
The decision index is also behind the live design:
- DR-038 describes the earlier service-link gain implementation rather than the selected fail-safe shunt topology;
- DR-039 is labelled CURRENT_IMPLEMENTED despite AE-044 showing the requirement remains valid but the present implementation requires requalification;
- AE-041 A1 matrix/control authority is not represented.

### Design Pack Index
The index stops its assurance-chain summary around AE-025 and describes DR-039 as implemented without the later requalification finding.

### Disposition
**CONFIGURATION-CONTROL PATCH REQUIRED BEFORE BASELINE OR MANUFACTURING RELEASE.**

This is documentation/configuration debt, not evidence that the live circuit should revert.

Recommended patch target:
1. Risk Register;
2. current_decision_index.yaml;
3. DESIGN_PACK_INDEX.md;
4. document authority if needed;
5. BOM notes where configuration state changes.

Do not patch these controlled files until an explicit reconciled change set is prepared and approved.

---

## 6. Pre-SPICE closure table

| Item | Disposition |
|---|---|
| Linked-stereo Lorlin vs dual-mono NKK conflict | CLOSED — AE-041 A1/live model wins |
| Matrix 4P4 vs 3P4T conflict | CLOSED — 3P4T A30403RNCB preferred |
| Exact EQ rotary MPN | OPEN — mechanical stack/knob confirmation |
| AT-VM95SP four-terminal topology | DOCUMENTED |
| AT-VM95SP internal return/body isolation | BENCH CHECK |
| Grado 78E published R/L/V values | SUFFICIENT FOR PRELIMINARY MODEL |
| Grado 78E terminal topology/isolation | BENCH CHECK |
| R909 direct bond | RETAIN PROVISIONALLY |
| C909 with R909 fitted | DNP |
| Ground-lift clamps | DNP |
| Risk/decision/design-pack registers | STALE — CONTROLLED PATCH REQUIRED |

---

## Confidence
- AE-041 A1 supersedes AE-040B for current control architecture: 100%
- NKK NR01 family electrically suitable for EQ control: 99%
- exact EQ MPN should remain open pending mechanical stack: 98%
- AT-VM95SP has four separately identified L+/L-/R+/R- terminals: 100%
- AT-VM95SP internal isolation requires bench confirmation: 98%
- Grado 78E electrical source values adequate for preliminary modelling: 95%
- Grado 78E terminal topology requires measurement: 99%
- C909 redundant when R909=0 Ohm is fitted: 100%
- controlled registers are stale relative to live architecture: 100%

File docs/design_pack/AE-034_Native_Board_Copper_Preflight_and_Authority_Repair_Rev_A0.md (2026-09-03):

# AE-034 — Native Board Copper Preflight and Authority Repair

**Revision:** A0  
**Status:** COPPER IMPLEMENTATION PRE-FLIGHT

AE-034 prevents blind editing of the native KiCad S-expression. Before creating the In1 0VA zone or In2 rail geometry, the actual board must disclose the exact net table, exact 0VA net number/name, actual four-layer state, current segment/via/zone counts and board-edge evidence.

KiCad zones bind to both textual net identity and numeric net identifiers. Guessing the numeric ID risks creating an incorrect or unconnected plane, so Foundry evidence rules require discovery from the authoritative native board before mutation.

AE-034 also repairs SR-043's direct-script import convention and records that its older `kicad_native_pipeline.py` manufacturing-hole statement is superseded by SR-040/SR-043.

Once the generated preflight proves a unique 0VA net and expected unrouted/four-layer state, the next patch may safely create the In1 0VA zone, In2 rail spine and first SCH101 critical routes. Rotary-dependent regions remain held.

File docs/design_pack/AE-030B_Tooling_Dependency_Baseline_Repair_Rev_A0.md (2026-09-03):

# AE-030B — Tooling Dependency Baseline Repair

**Revision:** A0  
**Status:** TOOLCHAIN / REPRODUCIBILITY REPAIR

## Finding

AE-030A introduced a legitimate dependency on PyYAML for the controlled
machine-readable BOM cost ledger, but `requirements.txt` still declared only
pytest.

A fresh virtual environment would therefore fail when running the BOM-cost
audit.

## Resolution

Add:

`PyYAML==6.0.3`

to the root requirements file.

Version 6.0.3 is pinned because it is the version validated on the current
Windows/Python 3.13 Shellac development environment.

## Why keep PyYAML

The cost ledger is configuration data, not an intentionally narrow audit-only
format. Using a real YAML parser is preferable to maintaining another partial
YAML implementation as the BOM/procurement model grows.

## Clean-clone implication

The controlled setup sequence is now expected to include:

`python -m pip install -r requirements.txt`

before build, audit or test execution.

A future production reproducibility gate may pin the remainder of the Python
toolchain more tightly; AE-030B only fixes the newly demonstrated missing
dependency.

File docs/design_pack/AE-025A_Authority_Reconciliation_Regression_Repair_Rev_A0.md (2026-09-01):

# AE-025A — Authority Reconciliation Regression Repair

**Revision:** A0  
**Status:** REPAIR

AE-025 introduced two regressions:

1. `authoritative_current_status` was written as a YAML block list, but AE-024A's
   deliberately narrow standard-library parser only reads top-level inline lists.
2. `baseline.branch` in the authoritative current decision index was changed from
   `main` to `develop`. That field describes the validated implementation baseline,
   not the working development branch.

AE-025A restores the intended semantics:

- scoped status vocabularies are expressed as inline lists;
- `baseline.branch` remains `main`;
- the temporary `authority_scope` line is removed from the decision index;
- working-on-`develop` guidance remains in README/design-pack documentation rather
  than corrupting baseline provenance.

No circuit, CAD, BOM or assurance model is changed.

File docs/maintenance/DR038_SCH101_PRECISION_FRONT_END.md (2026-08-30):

# DR-038 maintenance note

Default gain is approximately 18 dB. All four balanced gain legs must use the
same service configuration. After SCH101 service verify gain, CMRR, output DC
and replay-EQ response.

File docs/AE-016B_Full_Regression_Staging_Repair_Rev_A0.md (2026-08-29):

# AE-016B — Full Regression Staging Repair

AE-016 caused two premature implementation migrations: DR-038 in the central
SCH101 model and DR-039 in the SCH103 physical builder. AE-016A repaired the
first class and reduced failures from 24 to 17.

AE-016B restores SCH103 to the pre-DR039 physical baseline while retaining the
DR-039 analytical model and selected decision. Both DR-038 and DR-039 will be
implemented later as atomic CAD/dependency migrations.

Apply with `APPLY_UPDATE.bat`, then run `python -m pytest`. Do not commit unless
the suite is clean.

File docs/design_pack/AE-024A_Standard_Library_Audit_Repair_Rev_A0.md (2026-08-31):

# AE-024A — Standard-Library Audit Repair

**Revision:** A0  
**Status:** REPAIR

AE-024 incorrectly introduced an undeclared PyYAML dependency.

AE-024A removes that dependency completely. The audit now uses a deliberately
narrow standard-library parser for the two Shellac decision-control YAML files.

The parser is not a general YAML implementation; it understands only the
structures required by:

- `config/decisions/decision_status.yaml`
- `config/decisions/current_decision_index.yaml`

This keeps the read-only audit self-contained and prevents tooling drift.

## Apply

Replace the AE-024 files with this package, then run:

`python tools/ae024_design_record_audit.py`
`python -m pytest`

No package installation is required.

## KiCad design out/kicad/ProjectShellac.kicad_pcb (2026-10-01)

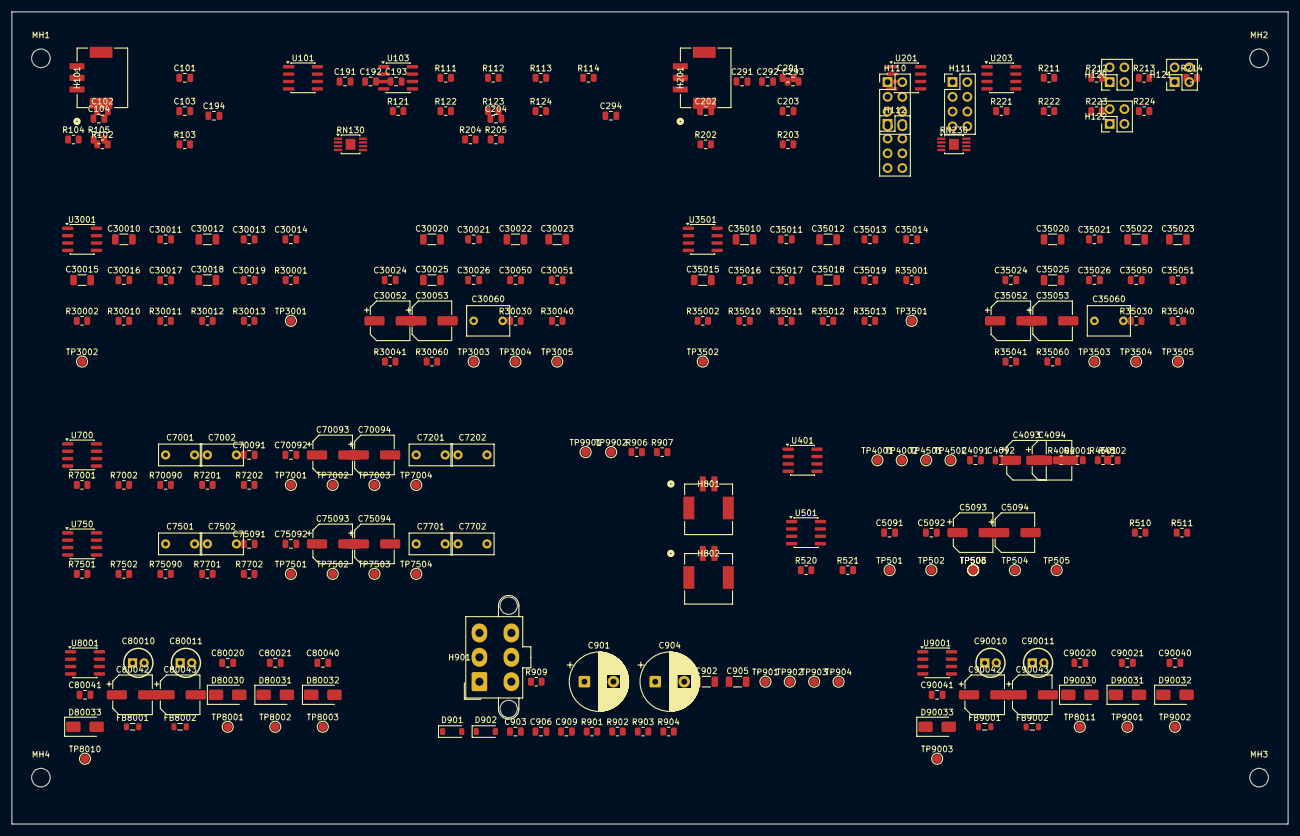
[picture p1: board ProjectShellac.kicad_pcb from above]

Board: 4 copper layers, 220.0 x 140.0 mm, 261 parts (0 on the bottom side), 114 nets, no tracks yet.

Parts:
C101, C102, C103, C201, C202, C203: 47p; C_0805_2012Metric
C104, C204, C80020, C80021, C90020, C90021: 100p; C_0805_2012Metric
C191, C192, C193, C194, C291, C292, C293, C294, C903, C906, C909, C4091, C4092, C5091, C5092, C30050, C30051, C35050, C35051, C70091, C70092, C75091, C75092, C80040, C80041, C90040, C90041: 100n; C_0805_2012Metric
C901, C904: 470u; CP_Radial_D10.0mm_P5.00mm
C902, C905: 1u; C_1206_3216Metric
C4093, C4094, C5093, C5094, C30052, C30053, C35052, C35053, C70093, C70094, C75093, C75094, C80042, C80043, C90042, C90043: 10u; CP_Elec_6.3x5.8
C7001, C7002, C7201, C7202, C7501, C7502, C7701, C7702: 470n; C_Rect_L7.2mm_W3.5mm_P5.00mm_FKS2_FKP2_MKS2_MKP2
C30010, C30012, C30015, C35010, C35012, C35015: 68n; C_1206_3216Metric
C30011, C35011: 5.6n; C_0805_2012Metric
C30013, C35013: 9.1n; C_0805_2012Metric
C30014, C35014: 560p; C_0805_2012Metric
C30016, C35016: 10n; C_0805_2012Metric
C30017, C35017: 470p; C_0805_2012Metric
C30018, C35018: 27n; C_1206_3216Metric
C30019, C35019: 2.4n; C_0805_2012Metric
C30020, C35020: 120n; C_1206_3216Metric
C30021, C35021: 12n; C_0805_2012Metric
C30022, C35022: 100n; C_1206_3216Metric
C30023, C35023: 56n; C_1206_3216Metric
C30024, C35024: 6.2n; C_0805_2012Metric
C30025, C35025: 33n; C_1206_3216Metric
C30026, C35026: 3.6n; C_0805_2012Metric
C30060, C35060: 1u; C_Rect_L7.2mm_W5.0mm_P5.00mm
C80010, C80011, C90010, C90011: 10u NP; Panasonic_ECEA1VN100U_D5.0mm_H11.0mm_P2.00mm
D901, D902: DNP; D_SOD-123
D80030, D80031, D80032, D80033, D90030, D90031, D90032, D90033: S1G; D_SMA
FB8001, FB8002, FB9001, FB9002: Ferrite bead; L_0805_2012Metric
H101: L INPUT HARNESS; Molex_MicroLockPlus_5055780321_1x03_P2.00mm_Horizontal
H110: GAIN LOW 4-GANG; PinHeader_2x04_P2.54mm_Vertical
H111: GAIN HIGH 4-GANG; PinHeader_2x04_P2.54mm_Vertical
H112: GAIN DEFAULT / PARK; PinHeader_2x04_P2.54mm_Vertical
H120: LOAD +47p L/R; PinHeader_2x02_P2.54mm_Vertical
H121: LOAD BASE / PARK; PinHeader_2x02_P2.54mm_Vertical
H122: LOAD +100p L/R; PinHeader_2x02_P2.54mm_Vertical
H201: R INPUT HARNESS; Molex_MicroLockPlus_5055780321_1x03_P2.00mm_Horizontal
H801: L OUTPUT HARNESS; Molex_MicroLockPlus_5055780221_1x02_P2.00mm_Horizontal
H802: R OUTPUT HARNESS; Molex_MicroLockPlus_5055780221_1x02_P2.00mm_Horizontal
H901: PCB DC HARNESS; Molex_Mini-Fit_Jr_5566-06A2_2x03_P4.20mm_Vertical
MH1, MH2, MH3, MH4: MountingHole_3.2mm_M3
R102, R103, R202, R203: 100R; R_0805_2012Metric
R104, R105, R204, R205: 23700; R_0805_2012Metric
R111, R121, R211, R221: 1000; R_0805_2012Metric
R112, R122, R212, R222: 999; R_0805_2012Metric
R113, R123, R213, R223: 332; R_0805_2012Metric
R114, R124, R214, R224: 866; R_0805_2012Metric
R510, R520: 2.2e+06; R_0805_2012Metric
R511, R521, R4001, R4501, R70090, R75090: 100; R_0805_2012Metric
R901, R902, R909: 0R; R_0805_2012Metric
R903, R904: 22k; R_0805_2012Metric
R906, R907, R30010, R30013, R35010, R35013: 8200; R_0805_2012Metric
R4002, R4502: 4700; R_0805_2012Metric
R7001, R7501: 20800; R_0805_2012Metric
R7002, R7502: 24300; R_0805_2012Metric
R7201, R7701: 8660; R_0805_2012Metric
R7202, R7702: 59000; R_0805_2012Metric
R30001, R35001: 100k; R_0805_2012Metric
R30002, R35002: 2.70k; R_0805_2012Metric
R30011, R35011: 2490; R_0805_2012Metric
R30012, R35012: 1430; R_0805_2012Metric
R30030, R35030: 750; R_0805_2012Metric
R30040, R35040: 10000; R_0805_2012Metric
R30041, R35041: 11000; R_0805_2012Metric
R30060, R35060: 330k; R_0805_2012Metric
RN130: L LT5400-7 1:4; MSOP-8-1EP_3x3mm_P0.65mm_EP1.68x1.88mm
RN230: R LT5400-7 1:4; MSOP-8-1EP_3x3mm_P0.65mm_EP1.68x1.88mm
TP501, TP8010: L_MODE_IN; TestPoint_Pad_D1.5mm
TP502, TP8011: R_MODE_IN; TestPoint_Pad_D1.5mm
TP503: MONO_AVG; TestPoint_Pad_D1.5mm
TP504: L_MODE_OUT; TestPoint_Pad_D1.5mm
TP505: R_MODE_OUT; TestPoint_Pad_D1.5mm
TP506: MONO_R_LEG; TestPoint_Pad_D1.5mm
TP901: +17VA_IN; TestPoint_Pad_D1.5mm
TP902: 0VA_IN; TestPoint_Pad_D1.5mm
TP903: -17VA_IN; TestPoint_Pad_D1.5mm
TP904: CHASSIS; TestPoint_Pad_D1.5mm
TP3001: L_EQ_IN; TestPoint_Pad_D1.5mm
TP3002: L_LF_EQ_OUT; TestPoint_Pad_D1.5mm
TP3003: L_HF_EQ_OUT; TestPoint_Pad_D1.5mm
TP3004: L_RECOVERY_OUT; TestPoint_Pad_D1.5mm
TP3005: L_POST_EQ; TestPoint_Pad_D1.5mm
TP3501: R_EQ_IN; TestPoint_Pad_D1.5mm
TP3502: R_LF_EQ_OUT; TestPoint_Pad_D1.5mm
TP3503: R_HF_EQ_OUT; TestPoint_Pad_D1.5mm
TP3504: R_RECOVERY_OUT; TestPoint_Pad_D1.5mm
TP3505: R_POST_EQ; TestPoint_Pad_D1.5mm
TP4001: L_BUFFER_IN; TestPoint_Pad_D1.5mm
TP4002: L_BUFFER_OUT; TestPoint_Pad_D1.5mm
TP4501: R_BUFFER_IN; TestPoint_Pad_D1.5mm
TP4502: R_BUFFER_OUT; TestPoint_Pad_D1.5mm
TP7001: L_RUMBLE_IN; TestPoint_Pad_D1.5mm
TP7002: L_HP1_OUT; TestPoint_Pad_D1.5mm
TP7003: L_HP2_OUT; TestPoint_Pad_D1.5mm
TP7004: L_RUMBLE_OUT; TestPoint_Pad_D1.5mm
TP7501: R_RUMBLE_IN; TestPoint_Pad_D1.5mm
TP7502: R_HP1_OUT; TestPoint_Pad_D1.5mm
TP7503: R_HP2_OUT; TestPoint_Pad_D1.5mm
TP7504: R_RUMBLE_OUT; TestPoint_Pad_D1.5mm
TP8001: L_DRIVER_IN; TestPoint_Pad_D1.5mm
TP8002: L_OUT_POS; TestPoint_Pad_D1.5mm
TP8003: L_OUT_NEG; TestPoint_Pad_D1.5mm
TP9001: R_DRIVER_IN; TestPoint_Pad_D1.5mm
TP9002: R_OUT_POS; TestPoint_Pad_D1.5mm
TP9003: R_OUT_NEG; TestPoint_Pad_D1.5mm
TP9901: +17V_LED_DRIVE; TestPoint_Pad_D1.5mm
TP9902: -17V_LED_DRIVE; TestPoint_Pad_D1.5mm
U101, U201, U401, U501, U700, U750: OPA1656; SOIC-8_3.9x4.9mm_P1.27mm
U103, U203: OPA1655; SOIC-8_3.9x4.9mm_P1.27mm
U3001, U3501: OPA1612; SOIC-8_3.9x4.9mm_P1.27mm
U8001: L THAT1646; SOIC-8_3.9x4.9mm_P1.27mm
U9001: R THAT1646; SOIC-8_3.9x4.9mm_P1.27mm

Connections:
0VA: C191.2, C192.1, C193.2, C194.1, C291.2, C292.1, C293.2, C294.1, C901.2, C902.2, C903.2, C904.1, C905.1, C906.1, C909.1, C4091.2, C4092.1, C4093.2, C4094.1, C5091.2, C5092.1, C5093.2, C5094.1, C30020.2, C30021.2, C30022.2, C30023.2, C30024.2, C30025.2, C30026.2, C30050.2, C30051.1, C30052.2, C30053.1, C35020.2, C35021.2, C35022.2, C35023.2, C35024.2, C35025.2, C35026.2, C35050.2, C35051.1, C35052.2, C35053.1, C70091.2, C70092.1, C70093.2, C70094.1, C75091.2, C75092.1, C75093.2, C75094.1, C80040.2, C80041.1, C80042.2, C80043.1, C90040.2, C90041.1, C90042.2, C90043.1, D901.1 (K), D902.2 (A), H111.2 (B1), H111.4 (B2), H111.6 (B3), H111.8 (B4), H901.1, R104.2, R105.1, R111.1, R121.1, R204.2, R205.1, R211.1, R221.1, R510.2, R520.2, R903.2, R904.1, R909.1, R7002.1, R7202.1, R7502.1, R7702.1, R30002.2, R30040.2, R30060.2, R35002.2, R35040.2, R35060.2, RN130.5, RN130.9 (EP), RN230.5, RN230.9 (EP), TP902.1 (TP), U8001.3 (GND), U9001.3 (GND)
+17V: C191.1, C193.1, C291.1, C293.1, C901.1, C902.1, C903.1, C4091.1, C4093.1, C5091.1, C5093.1, C30050.1, C30052.1, C35050.1, C35052.1, C70091.1, C70093.1, C75091.1, C75093.1, C80040.1, C80042.1, C90040.1, C90042.1, D80030.1 (K), D80032.1 (K), D90030.1 (K), D90032.1 (K), R901.2, R903.1, R906.2, U101.8 (+V), U103.7 (+V), U201.8 (+V), U203.7 (+V), U401.8 (+V), U501.8 (+V), U700.8 (+V), U750.8 (+V), U3001.8 (+V), U3501.8 (+V), U8001.6 (+V), U9001.6 (+V)
-17V: C192.2, C194.2, C292.2, C294.2, C904.2, C905.2, C906.2, C4092.2, C4094.2, C5092.2, C5094.2, C30051.2, C30053.2, C35051.2, C35053.2, C70092.2, C70094.2, C75092.2, C75094.2, C80041.2, C80043.2, C90041.2, C90043.2, D80031.2 (A), D80033.2 (A), D90031.2 (A), D90033.2 (A), R902.2, R904.2, R907.2, U101.4 (-V), U103.4 (-V), U201.4 (-V), U203.4 (-V), U401.4 (-V), U501.4 (-V), U700.4 (-V), U750.4 (-V), U3001.4 (-V), U3501.4 (-V), U8001.5 (-V), U9001.5 (-V)
/INPUT_L_NEG: H101.3, R103.1
/INPUT_L_POS: H101.2, R102.1
/INPUT_R_NEG: H201.3, R203.1
/INPUT_R_POS: H201.2, R202.1
/OUTPUT_L_NEG: C80021.1, D80032.2 (A), D80033.1 (K), FB8002.2, H801.2, TP8003.1 (TP)
/OUTPUT_L_POS: C80020.2, D80030.2 (A), D80031.1 (K), FB8001.2, H801.1, TP8002.1 (TP)
/OUTPUT_R_NEG: C90021.1, D90032.2 (A), D90033.1 (K), FB9002.2, H802.2, TP9003.1 (TP)
/OUTPUT_R_POS: C90020.2, D90030.2 (A), D90031.1 (K), FB9001.2, H802.1, TP9002.1 (TP)
/SCH101 Balanced Input and Differential Conversion/SCH101_L_LOAD47_BRANCH: C103.2, H120.1 (A1)
/SCH101 Balanced Input and Differential Conversion/SCH101_L_LOAD100_BRANCH: C104.2, H122.1 (A1)
/SCH101 Balanced Input and Differential Conversion/SCH101_L_LOAD_NEG: C102.2, H120.2 (B1), H122.2 (B1), R103.2, R105.2, U101.5 (IN+)
/SCH101 Balanced Input and Differential Conversion/SCH101_L_LOAD_POS: C101.1, C103.1, C104.1, R102.2, R104.1, U101.3 (IN+)
/SCH101 Balanced Input and Differential Conversion/SCH101_L_LT5400_MINUS_SRC: R122.2, R123.1, RN130.2, U101.7 (OUT)
/SCH101 Balanced Input and Differential Conversion/SCH101_L_LT5400_MINUS_SUM: RN130.1, RN130.7, U103.2 (IN-)
/SCH101 Balanced Input and Differential Conversion/SCH101_L_LT5400_PLUS_SRC: R112.2, R113.1, RN130.3, U101.1 (OUT)
/SCH101 Balanced Input and Differential Conversion/SCH101_L_LT5400_PLUS_SUM: RN130.4, RN130.6, U103.3 (IN+)
/SCH101 Balanced Input and Differential Conversion/SCH101_L_MINUS_FB: H110.4 (B2), R121.2, R122.1, R124.1, U101.6 (FB-)
/SCH101 Balanced Input and Differential Conversion/SCH101_L_MINUS_HIGH_BRANCH: H111.3 (A2), R124.2
/SCH101 Balanced Input and Differential Conversion/SCH101_L_MINUS_LOW_BRANCH: H110.3 (A2), R123.2
/SCH101 Balanced Input and Differential Conversion/SCH101_L_PLUS_FB: H110.2 (B1), R111.2, R112.1, R114.1, U101.2 (FB-)
/SCH101 Balanced Input and Differential Conversion/SCH101_L_PLUS_HIGH_BRANCH: H111.1 (A1), R114.2
/SCH101 Balanced Input and Differential Conversion/SCH101_L_PLUS_LOW_BRANCH: H110.1 (A1), R113.2
/SCH101 Balanced Input and Differential Conversion/SCH101_R_LOAD47_BRANCH: C203.2, H120.3 (A2)
/SCH101 Balanced Input and Differential Conversion/SCH101_R_LOAD100_BRANCH: C204.2, H122.3 (A2)
/SCH101 Balanced Input and Differential Conversion/SCH101_R_LOAD_NEG: C202.2, H120.4 (B2), H122.4 (B2), R203.2, R205.2, U201.5 (IN+)
/SCH101 Balanced Input and Differential Conversion/SCH101_R_LOAD_POS: C201.1, C203.1, C204.1, R202.2, R204.1, U201.3 (IN+)
/SCH101 Balanced Input and Differential Conversion/SCH101_R_LT5400_MINUS_SRC: R222.2, R223.1, RN230.2, U201.7 (OUT)
/SCH101 Balanced Input and Differential Conversion/SCH101_R_LT5400_MINUS_SUM: RN230.1, RN230.7, U203.2 (IN-)
/SCH101 Balanced Input and Differential Conversion/SCH101_R_LT5400_PLUS_SRC: R212.2, R213.1, RN230.3, U201.1 (OUT)
/SCH101 Balanced Input and Differential Conversion/SCH101_R_LT5400_PLUS_SUM: RN230.4, RN230.6, U203.3 (IN+)
/SCH101 Balanced Input and Differential Conversion/SCH101_R_MINUS_FB: H110.8 (B4), R221.2, R222.1, R224.1, U201.6 (FB-)
/SCH101 Balanced Input and Differential Conversion/SCH101_R_MINUS_HIGH_BRANCH: H111.7 (A4), R224.2
/SCH101 Balanced Input and Differential Conversion/SCH101_R_MINUS_LOW_BRANCH: H110.7 (A4), R223.2
/SCH101 Balanced Input and Differential Conversion/SCH101_R_PLUS_FB: H110.6 (B3), R211.2, R212.1, R214.1, U201.2 (FB-)
/SCH101 Balanced Input and Differential Conversion/SCH101_R_PLUS_HIGH_BRANCH: H111.5 (A3), R214.2
/SCH101 Balanced Input and Differential Conversion/SCH101_R_PLUS_LOW_BRANCH: H110.5 (A3), R213.2
/SCH106 Audio-Box Power Entry and Ground Bond/+17VA_IN: H901.2, R901.1, TP901.1 (TP)
/SCH106 Audio-Box Power Entry and Ground Bond/-17VA_IN: H901.3, R902.1, TP903.1 (TP)
CHASSIS: C101.2, C102.1, C201.2, C202.1, C909.2, C80020.1, C80021.2, C90020.1, C90021.2, D901.2 (A), D902.1 (K), H101.1, H201.1, H901.4, R909.2, TP904.1 (TP)
unnamed: C7001.1, C7002.2, R7001.1
unnamed: C7201.1, C7202.2, R7201.1
unnamed: C7501.1, C7502.2, R7501.1
unnamed: C7701.1, C7702.2, R7701.1
unnamed: C30010.1, C30011.1, R30010.2
unnamed: C30010.2, C30011.2
unnamed: C30012.1, C30013.1, C30014.1, R30011.2
unnamed: C30012.2, C30013.2, C30014.2
unnamed: C30015.1, C30016.1, C30017.1, R30012.2
unnamed: C30015.2, C30016.2, C30017.2
unnamed: C30018.1, C30019.1, R30013.2
unnamed: C30018.2, C30019.2
unnamed: C30020.1, C30021.1
unnamed: C30023.1, C30024.1
unnamed: C30025.1, C30026.1
unnamed: C30060.1, R30060.1
unnamed: C35010.1, C35011.1, R35010.2
unnamed: C35010.2, C35011.2
unnamed: C35012.1, C35013.1, C35014.1, R35011.2
unnamed: C35012.2, C35013.2, C35014.2
unnamed: C35015.1, C35016.1, C35017.1, R35012.2
unnamed: C35015.2, C35016.2, C35017.2
unnamed: C35018.1, C35019.1, R35013.2
unnamed: C35018.2, C35019.2
unnamed: C35020.1, C35021.1
unnamed: C35023.1, C35024.1
unnamed: C35025.1, C35026.1
unnamed: C35060.1, R35060.1
unnamed: R30001.1, R30010.1, R30011.1, R30012.1, R30013.1, R30030.1, TP3002.1 (TP), U3001.1 (OUT)
unnamed: R30030.2, TP3003.1 (TP), U3001.5 (IN+)
unnamed: R35001.1, R35010.1, R35011.1, R35012.1, R35013.1, R35030.1, TP3502.1 (TP), U3501.1 (OUT)
unnamed: R35030.2, TP3503.1 (TP), U3501.5 (IN+)
unnamed: C7201.2, R7001.2, TP7002.1 (TP), U700.1 (OUT), U700.2 (IN-)
unnamed: R7201.2, R70090.1, TP7003.1 (TP), U700.6 (IN-), U700.7 (OUT)
unnamed: C7701.2, R7501.2, TP7502.1 (TP), U750.1 (OUT), U750.2 (IN-)
unnamed: R7701.2, R75090.1, TP7503.1 (TP), U750.6 (IN-), U750.7 (OUT)
unnamed: TP8001.1 (TP), U8001.4 (IN)
unnamed: TP9001.1 (TP), U9001.4 (IN)
unnamed: R906.1, TP9901.1 (TP)
unnamed: R907.1, TP9902.1 (TP)
unnamed: R4001.1, U401.1 (OUT), U401.2 (IN-)
unnamed: R4501.1, U401.6 (IN-), U401.7 (OUT)
unnamed: R510.1, U501.3 (IN)
unnamed: R511.1, U501.1 (OUT), U501.2 (IN-)
unnamed: R520.1, U501.5 (IN)
unnamed: R521.1, U501.6 (IN-), U501.7 (OUT)
unnamed: C7002.1, R7002.2, U700.3 (IN)
unnamed: C7202.1, R7202.2, U700.5 (IN)
unnamed: C7502.1, R7502.2, U750.3 (IN)
unnamed: C7702.1, R7702.2, U750.5 (IN)
unnamed: R30001.2, R30002.1, U3001.2 (FB-)
unnamed: R30040.1, R30041.2, U3001.6 (FB-)
unnamed: R35001.2, R35002.1, U3501.2 (FB-)
unnamed: R35040.1, R35041.2, U3501.6 (FB-)
unnamed: C80010.1, FB8001.1, U8001.8 (OUT+)
unnamed: C80011.1, FB8002.1, U8001.1 (OUT-)
unnamed: C80010.2, U8001.7 (SNS+)
unnamed: C80011.2, U8001.2 (SNS-)
unnamed: C90010.1, FB9001.1, U9001.8 (OUT+)
unnamed: C90011.1, FB9002.1, U9001.1 (OUT-)
unnamed: C90010.2, U9001.7 (SNS+)
unnamed: C90011.2, U9001.2 (SNS-)
ROOT__BUFFERED_L: R4001.2, TP501.1 (TP), TP4002.1 (TP)
ROOT__BUFFERED_R: R4501.2, TP502.1 (TP), TP4502.1 (TP)
ROOT__FILTERED_L: TP4001.1 (TP), TP7004.1 (TP), U401.3 (IN)
ROOT__FILTERED_R: TP4501.1 (TP), TP7504.1 (TP), U401.5 (IN)
ROOT__MODE_L: R511.2, TP504.1 (TP), TP8010.1 (TP)
ROOT__MODE_R: R521.2, TP505.1 (TP), TP8011.1 (TP)
ROOT__POST_EQ_L: C7001.2, C30060.2, R30041.1, TP3004.1 (TP), TP3005.1 (TP), TP7001.1 (TP), U3001.7 (OUT)
ROOT__POST_EQ_R: C7501.2, C35060.2, R35041.1, TP3504.1 (TP), TP3505.1 (TP), TP7501.1 (TP), U3501.7 (OUT)
ROOT__PRE_EQ_L: RN130.8, TP3001.1 (TP), U103.6 (OUT), U3001.3 (IN+)
ROOT__PRE_EQ_R: RN230.8, TP3501.1 (TP), U203.6 (OUT), U3501.3 (IN+)

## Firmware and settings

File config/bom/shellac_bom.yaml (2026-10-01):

schema_version: 1
project: shellac
status: CONTROLLED_PARTIAL_BASELINE
reconciled_by: AE-075C
control_hardware_updated_by: AE-075C
bom_reviewed_by: DR-037
procurement_complete: false
selection_policy:
  optimise_whole_bom_cost: true
  prefer_commonality: true
  premium_part_requires_material_benefit: true
items:
- id: BOM-ENC-AUDIO
  function: audio_enclosure
  manufacturer: METCASE
  mpn: M5502119
  status: FROZEN
  decision: DEC-005
- id: BOM-ENC-PSU
  function: psu_enclosure
  manufacturer: METCASE
  mpn: M5502119
  status: FROZEN
  decision: DEC-006
- id: BOM-PSU-MAINS
  function: filtered_mains_entry_fuse_switch
  manufacturer: SCHURTER
  mpn: KMF1.1121.11
  status: FROZEN
  decision: DEC-007
- id: BOM-CTRL-BASS
  function: bass_characteristic_selector_dual_mono
  manufacturer: NKK
  mpn: NR01105ANG13-2C
  quantity: 2
  requirement: independent_L_R_5_position_BBM_gold
  configured_positions: 5
  status: EXACT_PART_SELECTED_B03_PHYSICAL_IMPLEMENTATION_OPEN
  authority_reconciled_by: AE-075C
  knob_colour: red
  knob: AT3009_flanged
  mounting: pcb_through_hole_bracket_no_threaded_bushing_flange_beneath_panel
  depth_behind_panel_mm: 10.5
  installed_panel_to_pcb_mm: 12.3
  physical_ownership: MAIN_AUDIO_PCB_DIRECT_SELECTED_PHYSICAL_MIGRATION_PENDING
  physical_architecture_reconciled_by: AE-076B
  control_module_partition_reconciled_by: AE-076B
  interconnect_family: NONE_SINGLE_MAIN_PCB
  note: AE-076B direct main-PCB ownership; NKK 12.3 mm relationship retained; footprint/XY/support stack and RUN10 remain open.
- id: BOM-CTRL-TREBLE
  function: treble_characteristic_selector_dual_mono
  manufacturer: NKK
  mpn: NR01105ANG13-2A
  quantity: 2
  requirement: independent_L_R_5_position_BBM_gold
  configured_positions: 5
  status: EXACT_PART_SELECTED_B03_PHYSICAL_IMPLEMENTATION_OPEN
  authority_reconciled_by: AE-075C
  knob_colour: black
  knob: AT3009_flanged
  mounting: pcb_through_hole_bracket_no_threaded_bushing_flange_beneath_panel
  depth_behind_panel_mm: 10.5
  installed_panel_to_pcb_mm: 12.3
  physical_ownership: MAIN_AUDIO_PCB_DIRECT_SELECTED_PHYSICAL_MIGRATION_PENDING
  physical_architecture_reconciled_by: AE-076B
  control_module_partition_reconciled_by: AE-076B
  interconnect_family: NONE_SINGLE_MAIN_PCB
  note: AE-076B direct main-PCB ownership; NKK 12.3 mm relationship retained; footprint/XY/support stack and RUN10 remain open.
- id: BOM-CTRL-CHANNEL
  function: channel_mode_selector
  manufacturer: C&K
  mpn: A30403RNCB
  fallback_manufacturer: TE/Alcoswitch
  fallback_mpn: MRJE3404
  quantity: 1
  requirement: 3P4T_4_position_BBM_non_shorting_low_level_gold
  configured_positions: 4
  status: PREFERRED_PART_SELECTED_PROCUREMENT_PARTIAL
  authority_reconciled_by: AE-041-A1
  knob_manufacturer: TE/Alcoswitch
  knob_mpn: KN900B1/4
  mounting: pcb_through_hole_plus_3/8-32_threaded_top_cover_bushing
  physical_ownership: MAIN_AUDIO_PCB_DIRECT_SELECTED_PHYSICAL_MIGRATION_PENDING
  physical_architecture_reconciled_by: AE-076B
  physical_partition: MAIN_AUDIO_PCB_DIRECT
  control_module_partition_reconciled_by: AE-076B
  interconnect_family: NONE_SINGLE_MAIN_PCB
  note: AE-076B direct main-PCB ownership; C&K installed-plane fit/footprint/XY remain open for AE-076B2 MCAD.
- id: BOM-MATRIX-SUM-R
  function: switched_mono_averaging_resistors
  manufacturer: OPEN
  mpn: OPEN
  quantity: 2
  resistance_ohm: 4700
  tolerance: 0.1%
  status: VALUE_FROZEN_PART_OPEN
  authority_reconciled_by: AE-041-A1
  placement: SCH104_OPA1656_outputs_before_100R_isolation
  topology: left_leg_to_MONO_AVG_permanent_right_leg_to_MONO_R_LEG_switched_only_in_L+R
- id: BOM-CTRL-RUMBLE
  function: rumble_filter_bypass
  manufacturer: C&K
  mpn: 7201SYCBE
  requirement: stereo_DPDT_BBM
  status: SELECTED
  decision: DEC-027
  mounting: pcb_through_hole_plus_1/4-40_threaded_top_cover_bushing
  physical_ownership: MAIN_AUDIO_PCB_DIRECT_SELECTED_PHYSICAL_MIGRATION_PENDING
  physical_architecture_reconciled_by: AE-076B
  physical_partition: MAIN_AUDIO_PCB_DIRECT
  control_module_partition_reconciled_by: AE-076B
  interconnect_family: NONE_SINGLE_MAIN_PCB
  note: AE-076B direct main-PCB ownership local to SCH107; installed-plane fit/footprint/XY remain open for AE-076B2 MCAD.
- id: BOM-CTRL-MUTE
  function: output_mute_command
  manufacturer: C&K
  mpn: 7201SYCBE
  requirement: stereo_DPDT_BBM
  status: SELECTED
  decision: DEC-027
  mounting: pcb_through_hole_plus_1/4-40_threaded_top_cover_bushing
  physical_ownership: MAIN_AUDIO_PCB_DIRECT_SELECTED_PHYSICAL_MIGRATION_PENDING
  physical_architecture_reconciled_by: AE-076B
  physical_partition: MAIN_AUDIO_PCB_DIRECT
  control_module_partition_reconciled_by: AE-076B
  interconnect_family: NONE_SINGLE_MAIN_PCB
  note: AE-076B direct main-PCB ownership immediately before THAT1646; installed-plane fit/footprint/XY remain open for AE-076B2 MCAD.
- id: BOM-LED-POS
  function: positive_rail_indicator
  manufacturer: Vishay
  mpn: TLLG4401
  bezel_manufacturer: Arcolectric / Bulgin
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

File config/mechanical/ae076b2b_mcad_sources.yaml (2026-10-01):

schema_version: 1
project: Shellac
authority: AE-076B2B
baseline_commit: 1e8702139db68ef42bd0c2dd414db99524948309
metcase_enclosure:
  mpn: M5502119
  product_page: https://www.metcase.co.uk/en/Unicase/M5502119.htm
  drawing_url: https://www.metcase.co.uk/en/Unicase/M5502119/M5502119.pdf
  drawing_filename: M5502119.pdf
  drawing_min_bytes: 100000
  drawing_source_authority: MANUFACTURER_OFFICIAL
  drawing_bytes: 216009
  drawing_sha256: 9df7cbf5ef4bf0ae666feea5bbbc06e1d870f1cf30ae2c7496e4901ef1a4657a
  controlled_drawing_dimensions_mm:
    external:
    - 260.0
    - 250.0
    - 90.2
    inside_width: 256.0
    internal_cover_height: 86.2
    pcb_slot_width: 241.01
    inside_face_depth: 229.0
    panel_thickness: 2.0
  step_filename: M5502119.stp
  step_status: AUTHENTICATED_MANUAL_DOWNLOAD_INGESTED
  step_expected_size_kb_from_product_page: 417
  step_sha256: 9bf09314db1e8ffb596c27cceecb932141d3e43ba8d5ca4998fd4d16411b91fa
  exact_step_ingested: true
  login_requirement_source: https://www.metcase.co.uk/en/technical-info/faq
  step_bytes: 426871
  geometry_reconciled_to_controlled_drawing: false
neutrik_assets:
  NC3FD-L-B-1:
    source_authority: MANUFACTURER_OFFICIAL
    product_page: https://www.neutrik.com/en/product/nc3fd-l-b-1
    download_url: https://www.neutrik.com/media/13342/download/d-nc3fd-l-b-1.stp?v=1
    filename: NC3FD-L-B-1.stp
    min_bytes: 30000
    bytes: 94399
    sha256: 553ec8674f18717f583cbf5f11182dccc19891356253cc4649e07301c67a5465
    redistribution: LOCAL_CACHE_ONLY_NOT_COMMITTED
  NC3MD-L-B-1:
    source_authority: MANUFACTURER_OFFICIAL
    product_page: https://www.neutrik.com/en/product/nc3md-l-b-1
    download_url: https://www.neutrik.com/media/14359/download/3-D%20NC3MD-L-1.stp?v=1
    filename: NC3MD-L-B-1.stp
    min_bytes: 30000
    bytes: 70948
    sha256: 43da1e9d5fc74cbec908b4e8b04daba871c02bdd8b9c94b6896da2304ee3c183
    redistribution: LOCAL_CACHE_ONLY_NOT_COMMITTED
  NC5FD-LX-B:
    source_authority: MANUFACTURER_OFFICIAL
    product_page: https://www.neutrik.com/en/product/nc5fd-lx-b
    download_url: https://www.neutrik.com/media/11871/download/nc5fd-lx-1.stp?v=1
    filename: NC5FD-LX-B.stp
    min_bytes: 30000
    bytes: 118484
    sha256: 93927abde3aa2b4b0e596ddc1053e826e2143f8dfc85d8fb7c9567029a719336
    redistribution: LOCAL_CACHE_ONLY_NOT_COMMITTED
  NC5MD-LX-B:
    source_authority: MANUFACTURER_OFFICIAL
    product_page: https://www.neutrik.com/en/product/nc5md-lx-b
    download_url: https://www.neutrik.com/media/11874/download/3-D%20NC5MD-LX.stp?v=2
    filename: NC5MD-LX-B.stp
    min_bytes: 30000
    bytes: 94628
    sha256: 5c9f2e7c067f5df17f86caccbdaa023d29ca2a73a63ab204d3059cba590be965
    redistribution: LOCAL_CACHE_ONLY_NOT_COMMITTED
pcb_step:
  source_commit: 1e8702139db68ef42bd0c2dd414db99524948309
  source_board: out/kicad/ProjectShellac.kicad_pcb
  source_board_sha256: 2e8934d9357f85cda82a47e7a19524c5fd76b1d8357f6c2a95cfaa559b0b1417
  filename: ProjectShellac_AE076B2A.step
  tracked: false
  kicad_version: 9.0.7
  export_status: PASS_WITH_MISSING_3D_MODELS
  bytes: 1711778
  observed_sha256: 9e391adf01377ebdb3b58b5cd36bee400b8df176be434acb723e95324fad2646
  reproduction_tool: tools/prepare_ae076b2b_mcad_inputs.py
  missing_3d_model_refs:
  - C30060
  - C35060
  - H901
  geometry_complete: false
regulated_dc_interface:
  audio_chassis_receptacle: NC5MD-LX-B
  psu_chassis_receptacle: NC5FD-LX-B
  cable_audio_end: NC5FXX-B
  cable_psu_end: NC5MXX-B
  pin_contract:
    1: 0VA
    2: +17VA_IN
    3: -17VA_IN
    4: CHASSIS
    5: NC_RESERVED
  panel_shell_node: CHASSIS
  pin1_to_shell_bond: PROHIBITED
  generic_dmx_cable_substitution: PROHIBITED_UNLESS_PINOUT_CONTINUITY_VERIFIED
  mandatory_label: SHELLAC +/-17 V DC ONLY
gates:
  enclosure_drawing_hash_controlled: true
  metcase_exact_step_ingested: true
  neutrik_panel_geometry_hash_controlled: true
  pcb_step_generated: true
  rear_dc_connector_selected: true
  full_dimensional_assembly_authorized: false
  ck_control_geometry_complete: false
  six_support_geometry_frozen: false
  native_pcb_mechanical_migration_authorized: false
  routing_authority: false
  layout_freeze: false
  manufacturing_release: false
  metcase_step_geometry_reconciled: false
  pcb_step_geometry_complete: false

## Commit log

2026-07-03 Initial Project Shellac generator framework
2026-07-21 Baseline current Project Shellac generator and engineering model
2026-07-21 feat(replay): decompose SCH103 physical capacitors
2026-07-21 refactor(parts): centralise timing capacitor footprint policy
2026-08-17 feat(layout): close 10u capacitor physical identities
2026-08-24 feat(g3): freeze optional RIAA circuit and CI
2026-08-25 feat(g3): audit independent RIAA integration and BOM sourcing
2026-08-29 feat(signal-chain): restore legacy complete RIAA architecture
2026-08-29 analysis(signal-chain): close all-state gain and headroom envelope
2026-08-29 analysis(signal-chain): close noise review and identify DC-block requirement
2026-08-29 fix(signal-chain): stage DR-038 and DR-039 for atomic CAD migration
2026-08-30 analysis(cad): freeze LT5400 precision primitive contract
2026-08-30 feat(signal-chain): close validated DR-039 and DR-038 migrations
2026-08-30 release(schematic): close SR-039 schematic-to-layout gate
2026-08-30 feat(pcb): establish SR-042 native KiCad board baseline
    [ProjectShellac.kicad_pcb]
2026-08-30 wip(pcb): snapshot SR-043 native placement and mechanical audit
    [ProjectShellac.kicad_pcb]
2026-08-31 analysis(signal-chain): close production assurance baseline
2026-09-01 docs(control): reconcile current authority and historical evidence
2026-09-03 analysis(production): baseline readiness routing and BOM cost controls
2026-09-03 layout(native): configure four-layer board and copper preflight
2026-09-04 audit(production): protect native PCB and baseline integrity findings
2026-09-04 cad(opamps): reconcile physical dual-package population
2026-09-04 cad(opamps): implement real multi-unit pin semantics
    [diff.txt]
2026-09-04 governance(review): establish independent design assurance framework
2026-09-14 Reconcile SCH108 clamp diode and SPICE model
2026-09-15 AE-066: qualify RUN01-RUN03 and consolidate simulation infrastructure
    [ae066_summary.csv]
2026-09-15 AE-067: qualify RUN04 and select branch-local DR039 topology
    [ae067_run04.csv]
2026-09-15 AE-068: qualify RUN05 SCH104/SCH105 matrix
    [ae068_run05.csv]
2026-09-15 AE-069: complete RUN06 simulation evidence with bench gates
    [ae069_run06.csv]
2026-09-16 AE-070: qualify RUN07 and repair phase evidence
    [ae070_run07.csv]
2026-09-17 AE-071A: migrate SCH101 product architecture and reconcile native PCB
    [ProjectShellac.kicad_pcb]
2026-09-17 AE-071B: harden native PCB mechanical ownership
    [ProjectShellac.kicad_pcb]
2026-09-25 AE-073: close PSU long-settle discriminator and reconcile authority
    [long_settle_summary.csv, run01_400ms_load_trim_summary.csv, run01_400ms_servo_topology_summary.csv]
2026-09-27 AE-074: migrate DR-039 branch-local DC block and reconcile native PCB
    [ProjectShellac.kicad_pcb]
2026-09-28 AE-075: close B07 cartridge input harness and Micro-Lock migration
    [ProjectShellac.kicad_pcb]
2026-09-28 AE-075A: reconcile post-SR043 placement and close B05 sense capacitor
    [ProjectShellac.kicad_pcb]
2026-09-28 AE-075B: reconcile XLR LT5400 service hardware and authority debt
    [ProjectShellac.kicad_pcb]
2026-09-28 AE-075E: select distributed local C&K control PCBs
2026-09-30 AE-075G: reconcile output interface and PRE90 evidence
    [ProjectShellac.kicad_pcb]
2026-10-01 AE-076A: establish 17 V rail authority and requalify output
    [ProjectShellac.kicad_pcb]
2026-10-01 AE-076B: select single-PCB upper-cover service architecture
2026-10-01 AE-076B2A: select PCB face strategy
2026-10-15 AE-076F4T: select seven-control mounting methods without fabrication release
2026-10-26 AE-076F5Y: qualify KiCad 10 native configuration
2026-11-03 AE-076F7G: reconcile current working state and historical authority
